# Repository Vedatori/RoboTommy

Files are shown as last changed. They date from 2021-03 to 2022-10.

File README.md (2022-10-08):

# Multifunkční robotická platforma RoboTommy
RoboTommy je open source projekt zamýšlený jako univerzální platforma pro začátečníky v robotice, elektronice a programování. Při návrhu byl kladen důraz na široké možnosti robota v kombinaci s nízkými nároky na kutila.

RoboTommy byl vytvořen jako projekt pro robotické lekce a letní tábory v SVČ Lužánky v Brně. Autory jsou Martin Ptáček, Petr Vávra, Martin Coufal a Marek Coufal.

Robotická platforma je založena na 3D tištěném šasi se dvěma DC motory řízenými H můstkem. Jako řídicí jednotka byla použita kombinace mikrokontrolérů Arduino Nano Atmega328 a Wemos D1 Mini ESP8266.

Pro přidání vlastních functionalit nebo upravení designu se přihlašte na onshape.com a vyhledejte si projekt "RoboTommy". Pro zobrazení elektronických schémat nebo upravení základní desky, navštivte [easyeda.com](https://easyeda.com/technika/Arduino_Nano_ESP_MPU_board-965e335938244bc3aa54cd378a177850).

## Licence

* Obsah tohoto repozitáře mimo složku *Software* je sdílen pod licencí [Attribution-NonCommercial-ShareAlike 4.0 International (CC BY-NC-SA 4.0)](https://creativecommons.org/licenses/by-nc-sa/4.0/).

* Obsah složky *Software* je sdílen pod licencí [GNU Lesser General Public License v3.0](https://www.gnu.org/licenses/lgpl-3.0.en.html).

# Multifunctional robotics platform RoboTommy [en]
RoboTommy is an open source project devoted to be a universal platform 
for robotics, electronics and programming beginners. In construction 
emphasis was placed on broad capabilities of the robot in combination 
with low demands on the tinkerer.

RoboTommy was created as a support tool for robotics classes and summer 
camps in SVC Luzanky in Brno by Martin Ptacek, Petr Vavra, Martin Coufal and Marek Coufal.

This robotics platform is based upon a 3D printed differential chassis with two 
DC engines controlled by a H bridge. For control purposes a combination of 
Aruino Nano Atmega328 and Wemos D1 Mini ESP8266 microcontrollers is used.

To add custom mechanical features or edit RoboTommy please visit onshape.com, log in and search for the "RoboTommy" project. To check the electronical schematics and control the MainBoard layout, please visit [easyeda.com](https://easyeda.com/technika/Arduino_Nano_ESP_MPU_board-965e335938244bc3aa54cd378a177850).

## License
* The contents of this repository excluding folder *Software* is shared under license [Attribution-NonCommercial-ShareAlike 4.0 International (CC BY-NC-SA 4.0)](https://creativecommons.org/licenses/by-nc-sa/4.0/).
* The contents of the folder *Software* is shared under license [GNU Lesser General Public License v3.0](https://www.gnu.org/licenses/lgpl-3.0.en.html).

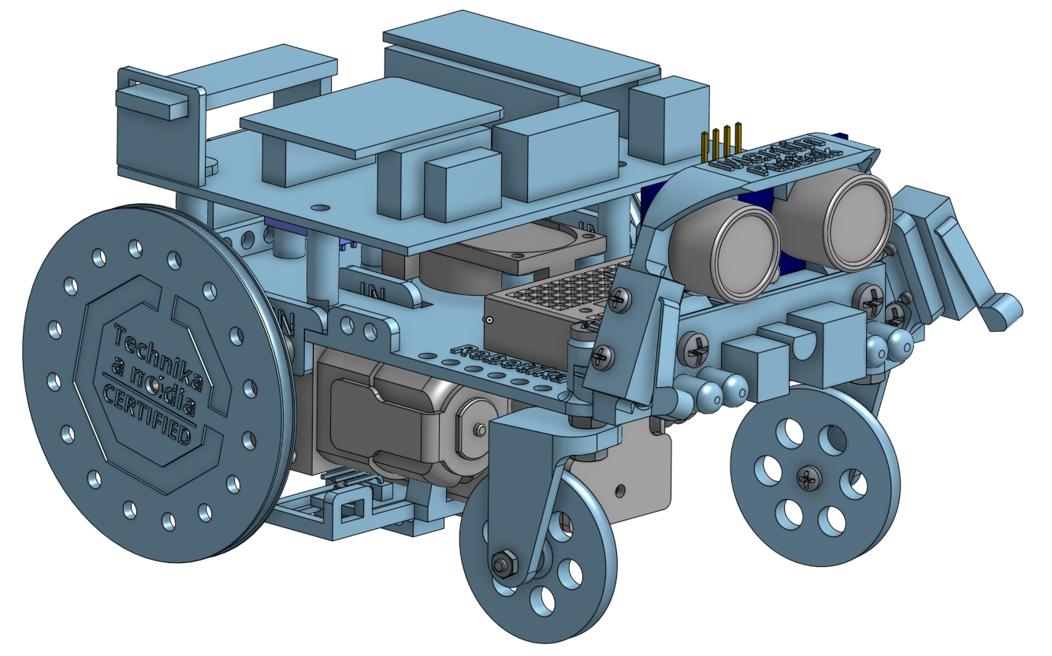
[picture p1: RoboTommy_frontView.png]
1.

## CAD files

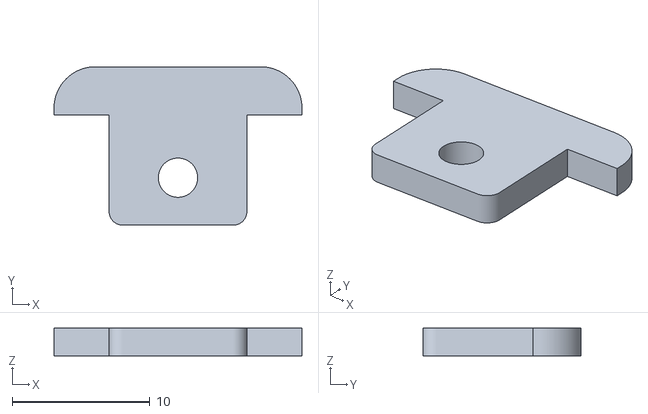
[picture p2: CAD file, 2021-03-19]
3DPrintParts_OnShape/EngineHolderIn.stl
18.0 x 11.5 x 2.00

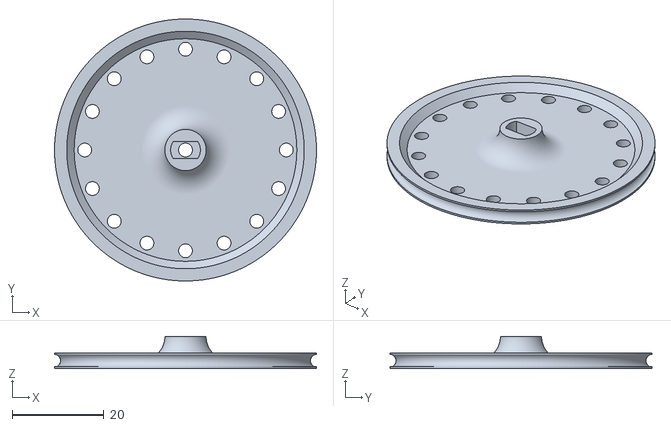
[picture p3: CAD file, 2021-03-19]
3DPrintParts_OnShape/RearWheel - Part 1 (5).stl
57.2 x 57.2 x 7.00

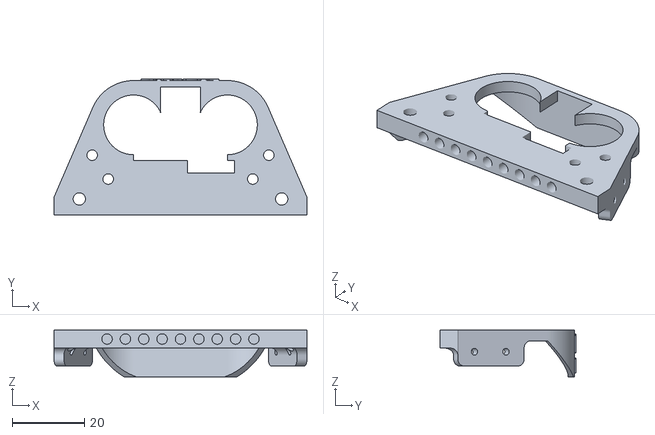
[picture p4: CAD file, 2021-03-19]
3DPrintParts_OnShape/UltrasonicHolder - Part 1 (2).stl
70.0 x 37.7 x 13.0

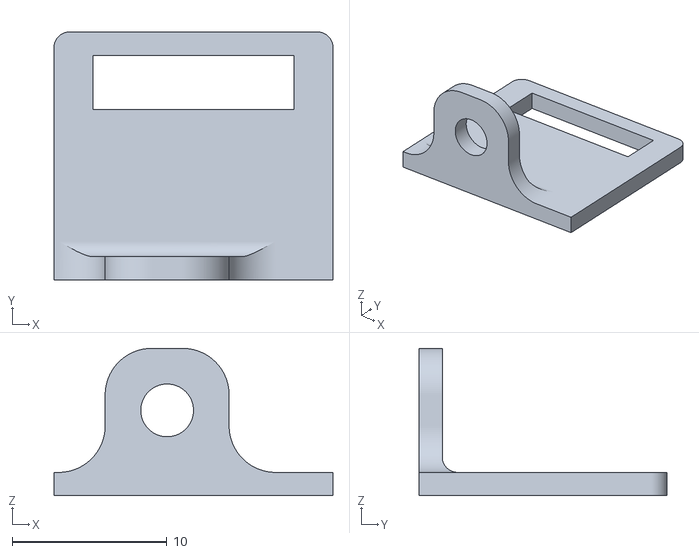
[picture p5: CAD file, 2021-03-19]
3DPrintParts_OnShape/DisplayHolder - Part 1.stl
18.0 x 16.0 x 9.50

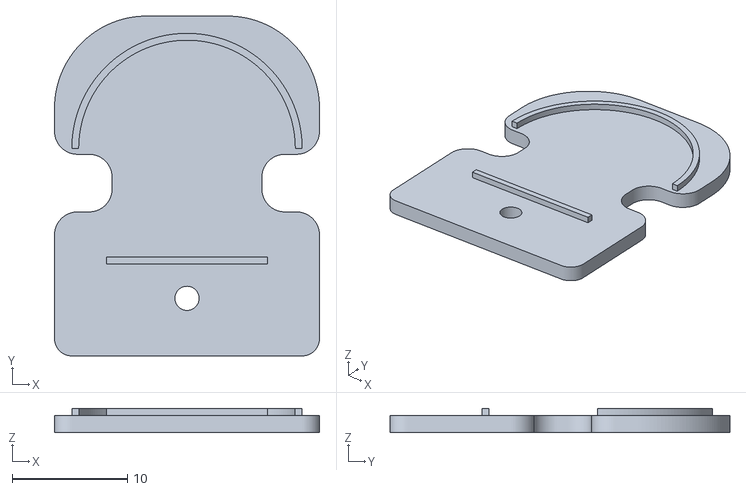
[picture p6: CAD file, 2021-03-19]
3DPrintParts_OnShape/PowerPackCover.stl
23.0 x 29.5 x 2.10

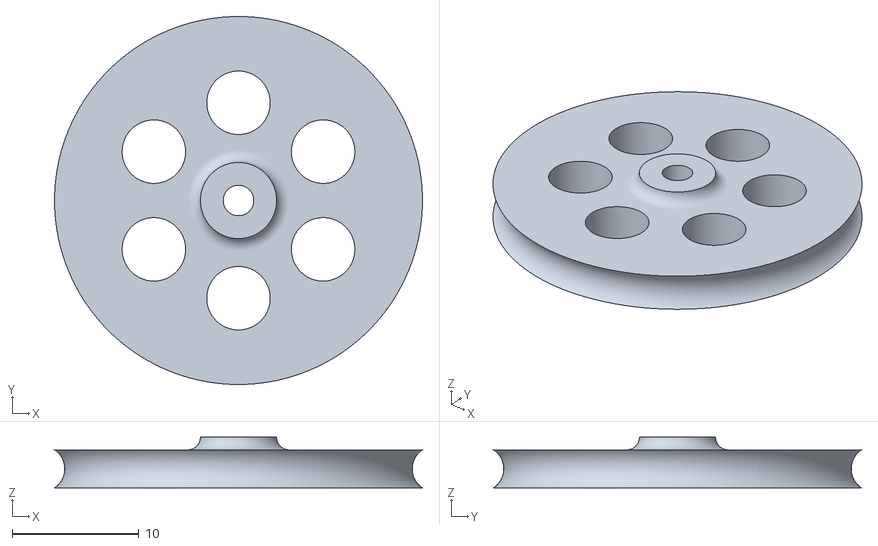
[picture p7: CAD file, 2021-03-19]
3DPrintParts_OnShape/FrontWheel - Part 1 (4).stl
29.0 x 29.0 x 4.00

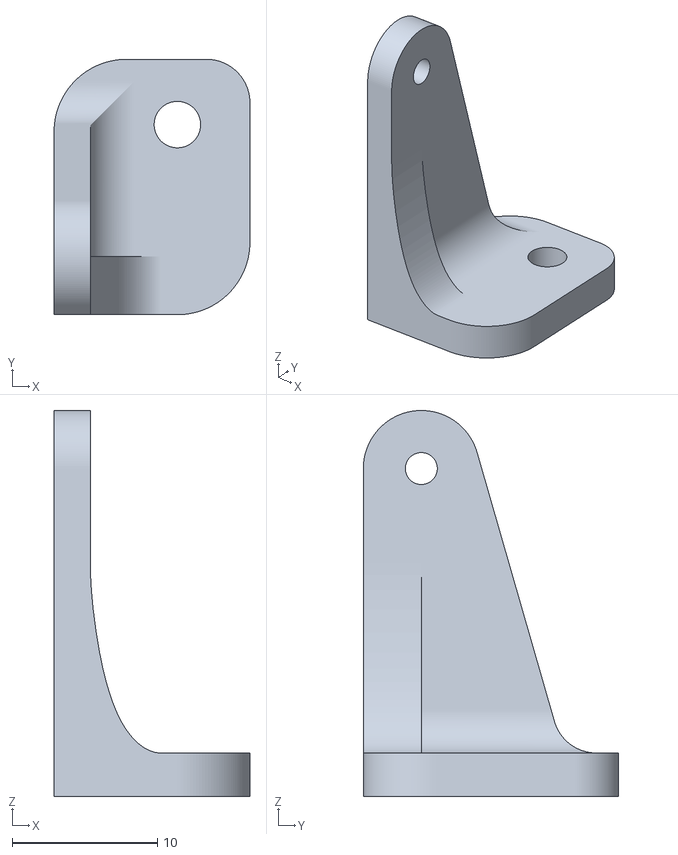
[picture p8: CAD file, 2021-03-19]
3DPrintParts_OnShape/FrontWheelHolder - Part 1 (1).stl
13.5 x 17.6 x 26.6

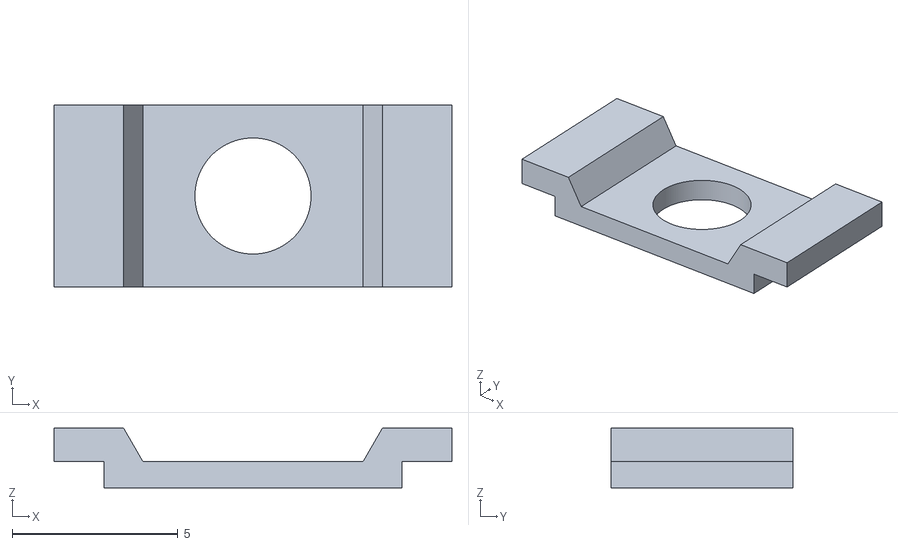
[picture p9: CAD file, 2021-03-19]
3DPrintParts_OnShape/CNY70Fastener - Part 1.stl
12.0 x 5.50 x 1.80

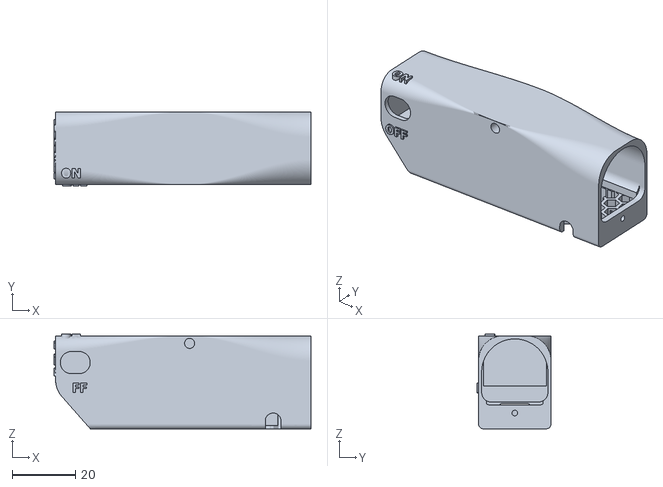
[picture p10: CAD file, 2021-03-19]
3DPrintParts_OnShape/PowerPackHolder.stl
81.5 x 23.5 x 30.0

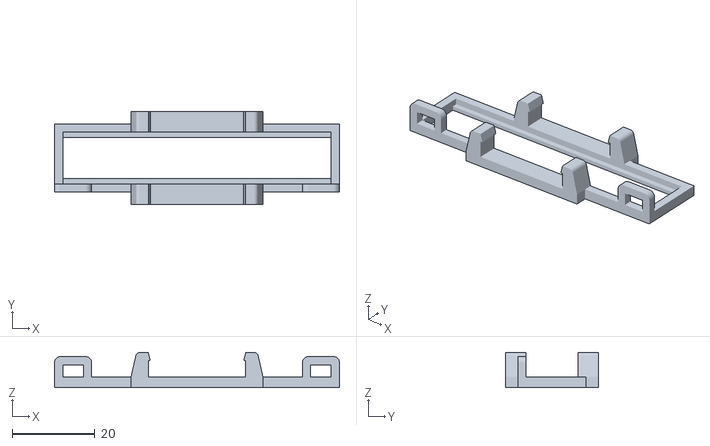
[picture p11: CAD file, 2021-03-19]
3DPrintParts_OnShape/CNY70Holder - Part 1 (1).stl
69.0 x 22.5 x 8.50

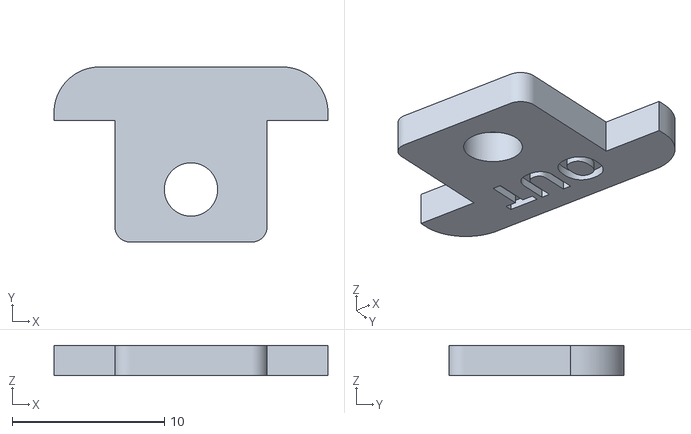
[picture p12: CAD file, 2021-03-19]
3DPrintParts_OnShape/EngineHolderOut.stl
18.0 x 11.5 x 2.00

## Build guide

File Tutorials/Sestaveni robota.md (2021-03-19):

# Montáž minimální konfigurace RoboTommy

*TODO: Doplnit rozměry šroubů, názvy korespodujících stl součástí, názvy elektronických součástí + whereToBuy*
## Součásti

1. **2x kolo, gumička, šroubek**
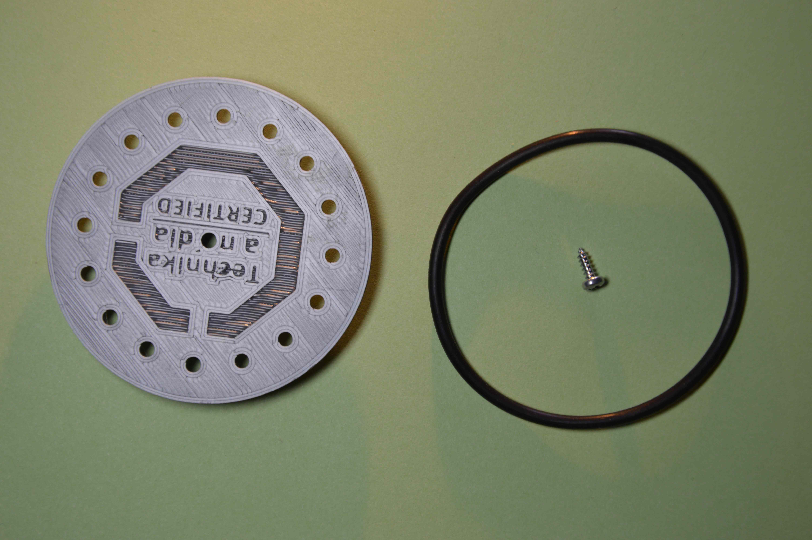
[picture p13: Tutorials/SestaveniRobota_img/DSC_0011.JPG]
    
2. **1x Main Board**

    *povinné součásti pro funkčnost*
    1. svorky napájení 
    2. svorky motorů
    3. připájený DRV 8833 Motor Driver
    4. dutinkové lišty pro Arduino Nano + Arduino Nano
    5. 3x šrouby pro připevnění na nosnou desku
   
    *volitelné součásti*
    1. Senzor vlhkosti a teploty DHT12
    2. dutinkové lišty pro Wemos D1 MINI + Zenerovy diody a odpory + Wemos D1 MINI
    3. dutinkové lišty pro gyroskop (napájené zespodu) + gyroskop
    4. Gesture senzor
    5. OLED displej 128x32

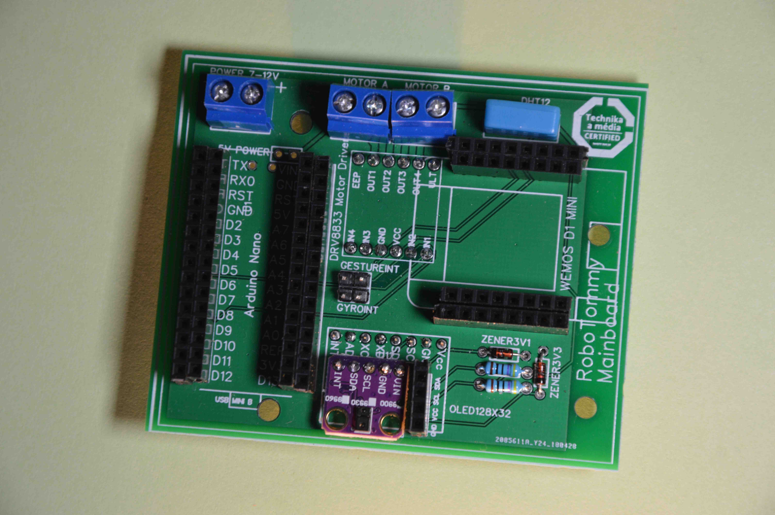
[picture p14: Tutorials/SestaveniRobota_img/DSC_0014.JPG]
    
3. **1x nosná deska s nepájivým polem**
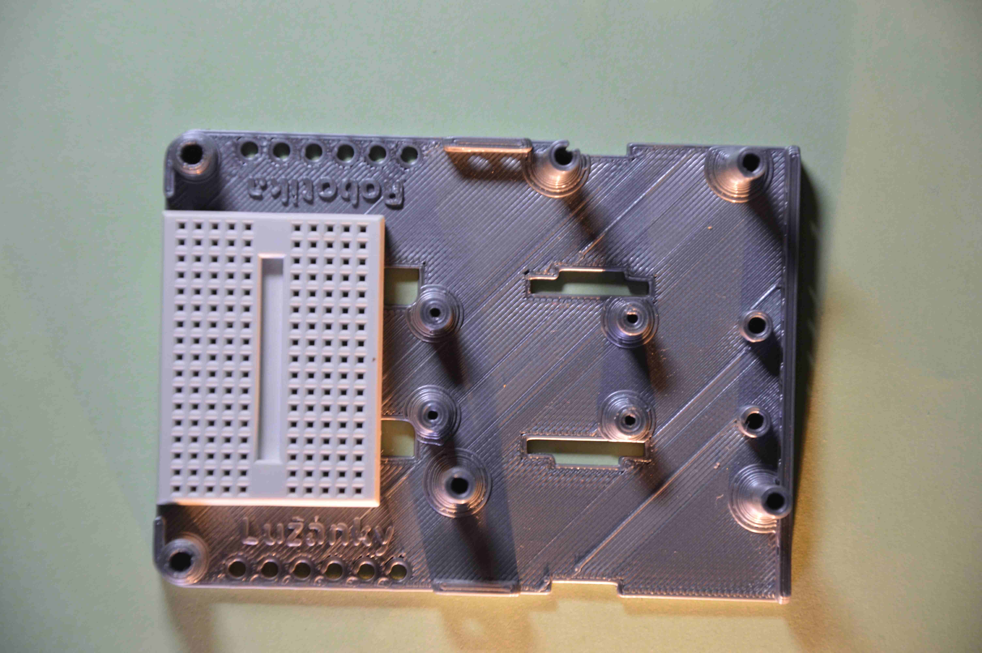
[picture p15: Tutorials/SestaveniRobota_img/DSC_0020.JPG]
    
4. **1x Power Pack** 
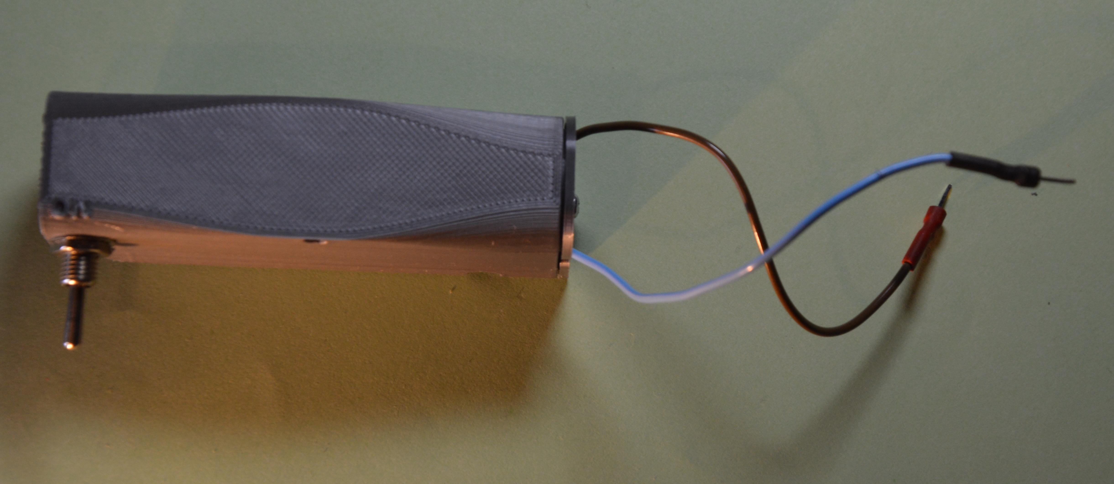
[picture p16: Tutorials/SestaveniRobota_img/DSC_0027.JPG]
    
5. **2x motor, 4x úchyt, 2x uchycovací šroub a matka**
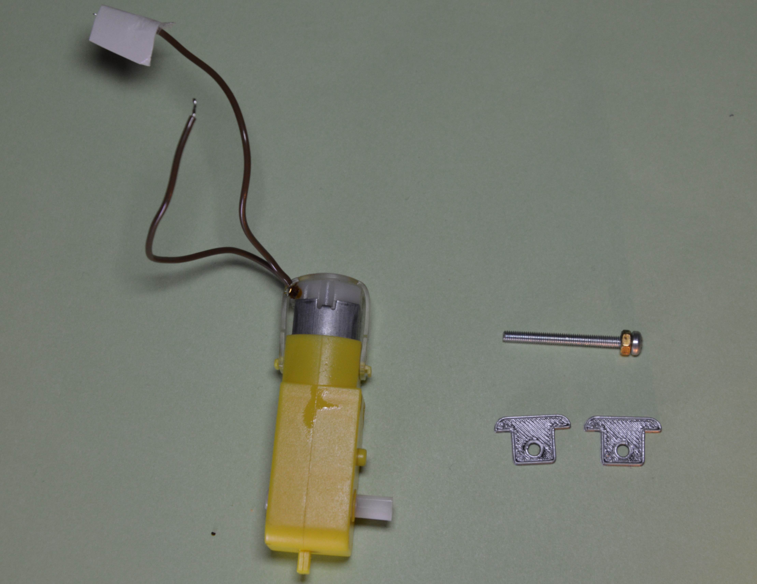
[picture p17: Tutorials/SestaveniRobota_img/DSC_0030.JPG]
    
6. **2x závěs předního kola, 2x kolo, 2x uchycovací šroub, 4x matka, 2x gumička, 2x uchycovací šroub, 4x matka**
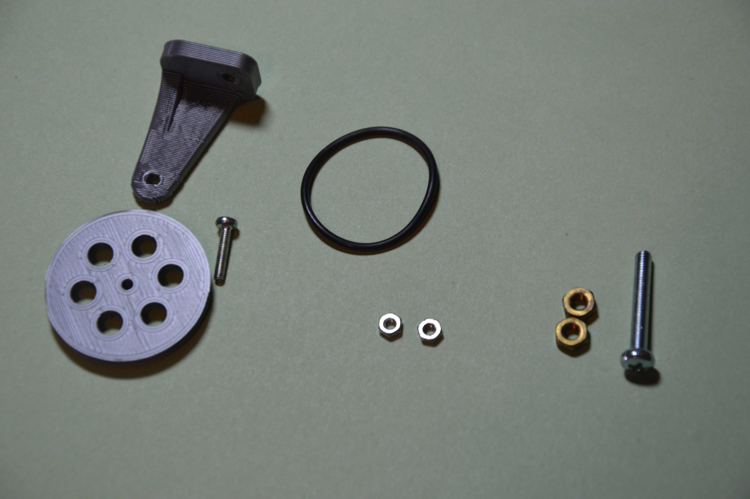
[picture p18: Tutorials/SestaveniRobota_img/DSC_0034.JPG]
    

## Proces montáže

### Montáž závěsu předního kola

Pro tuto část je třeba součásti z bodů 6 a 1 části Součásti tohoto dokumentu.

<<<<<<< HEAD
1. Navléct gumičku na kolo, provléct šroub kolem, z druhé strany našroubovat matku. *Matka nebude v kontaktu s kolem, je nutné zachovat malou mezeru.*
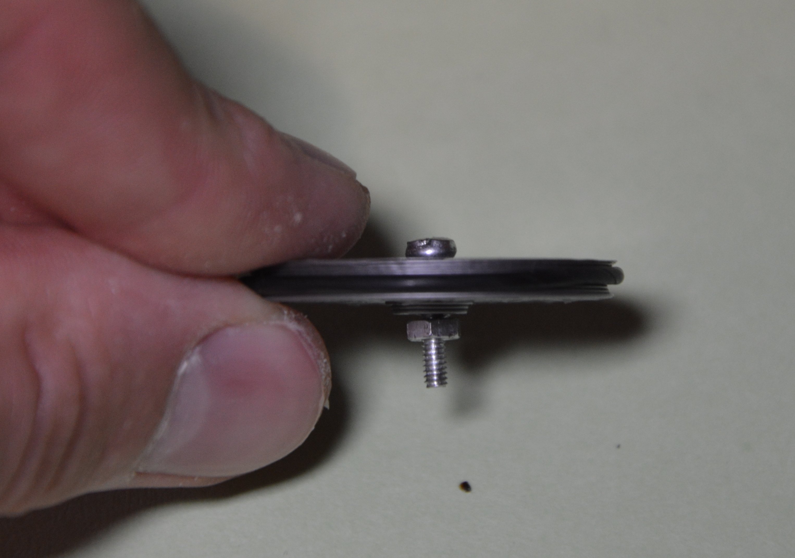
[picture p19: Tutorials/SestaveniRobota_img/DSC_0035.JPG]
    
=======
1. Navléct gumičku, provléct šroub kolem, z druhé strany našroubovat matku. *Matka nebude v kontaktu s kolem, je nutné zachovat malou mezeru.*
    
>>>>>>> fd59f11337bc10f44106d7633502139bb4ab0da0
2. Konec šroubu provléct závěsem a na konci přišroubovat matku. *Obě matky budou dotaženy ve směru šipek na obrázku, směrem k závěsu kola, kolo by se mělo volně protáčet.*
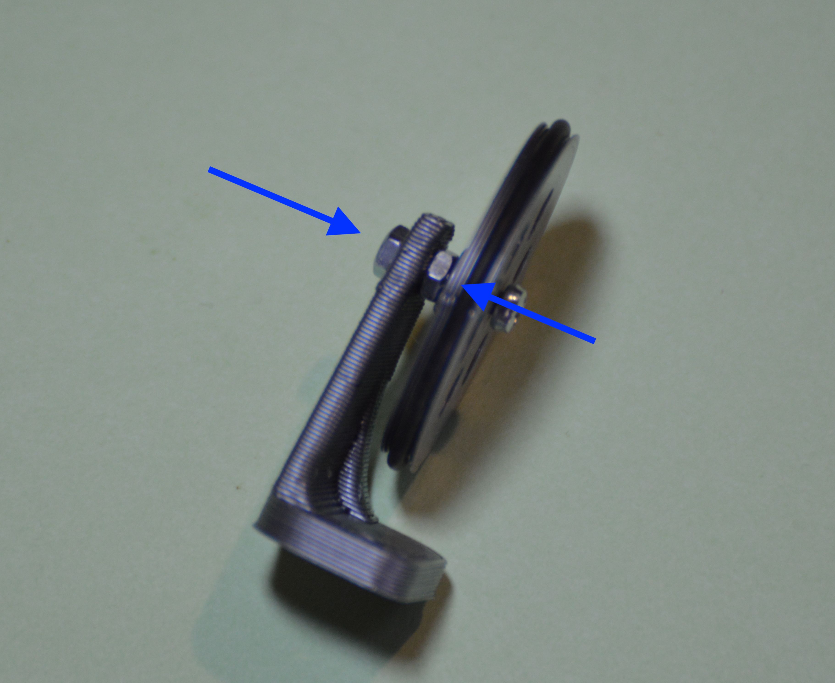
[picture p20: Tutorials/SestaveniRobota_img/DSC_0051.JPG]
    
3. Nosnou deskou protáhnout šroub, přšroubovat na něj matku. *Matka nebude v kontaktu s deskou, je nutné zachovat malou mezeru. Šroub se musí v desce volně protáčet.*
<<<<<<< HEAD
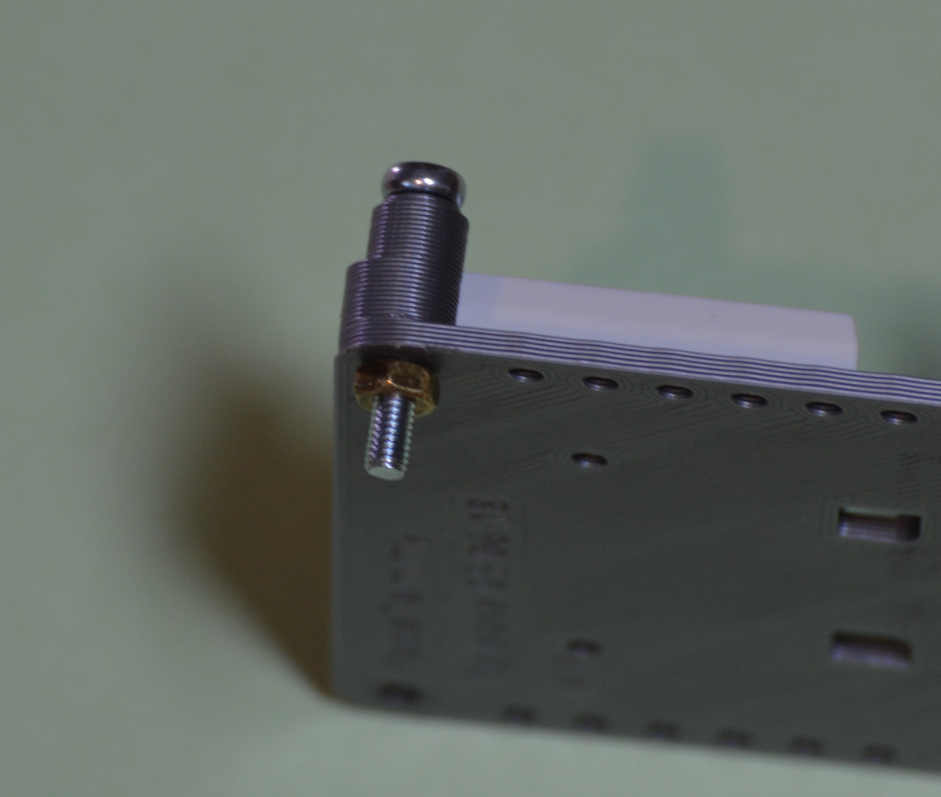
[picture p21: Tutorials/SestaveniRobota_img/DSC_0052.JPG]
    
4. Za matku navléct na šroub závěs kola a dotáhnout matky, aby byly v kontaktu pouze se závěsem a šroub se mohl v nosné desce volně protáčet.
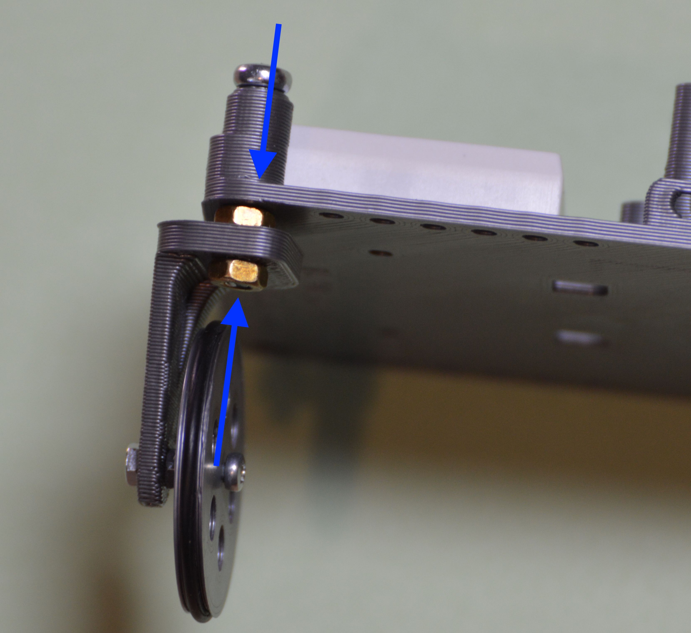
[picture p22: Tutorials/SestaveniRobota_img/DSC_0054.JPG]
    
=======
    
4. Za matku navláct na šroub závěs kola a dotáhnout matky, aby byly v kontaktu pouze se závěsema a šroub se mohl v nosné desce volně protáčet.
    
>>>>>>> fd59f11337bc10f44106d7633502139bb4ab0da0
5. **Postup opakovat pro druhé přední kolo.**
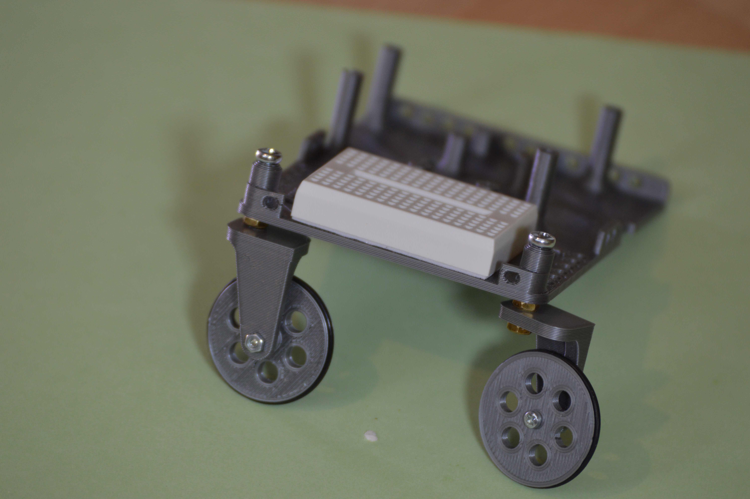
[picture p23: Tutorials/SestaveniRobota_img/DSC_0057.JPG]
    

### Montáž motorů, zadních kol a Power Packu

<<<<<<< HEAD
1. Nosnou desku nasměrovat trubičkami pro uchycení šroubů k zemi. 
2. Na šroub namontovat matku a jeden úchyt, tuto sestavu umístit do odpovídajícho výřezu na nosné desce. Šroub protáhnout skrze motor. *Vodič, který je na motoru nyní blíže k nosné desce, označit páskou.*  Z motoru odvést vodiče skrze přilehlou díru na druhou stranu nosné desky. 
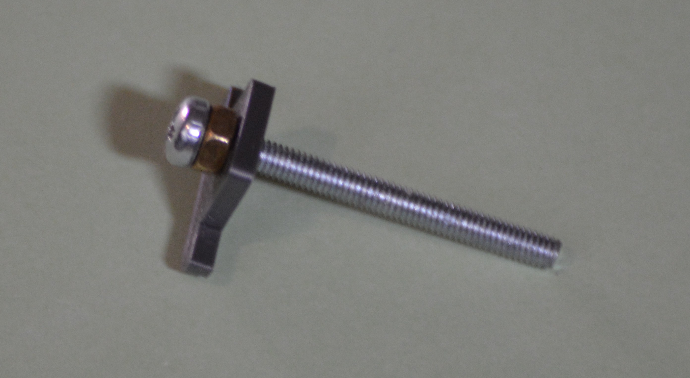
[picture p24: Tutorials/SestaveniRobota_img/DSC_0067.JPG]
    
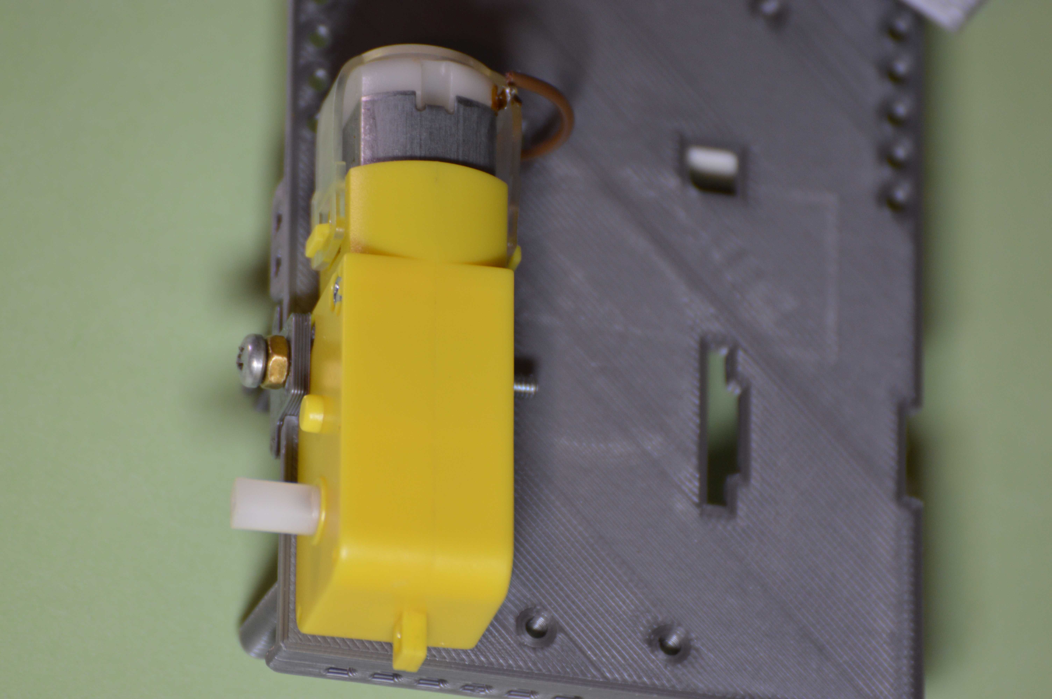
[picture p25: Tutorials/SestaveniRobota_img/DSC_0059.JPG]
    
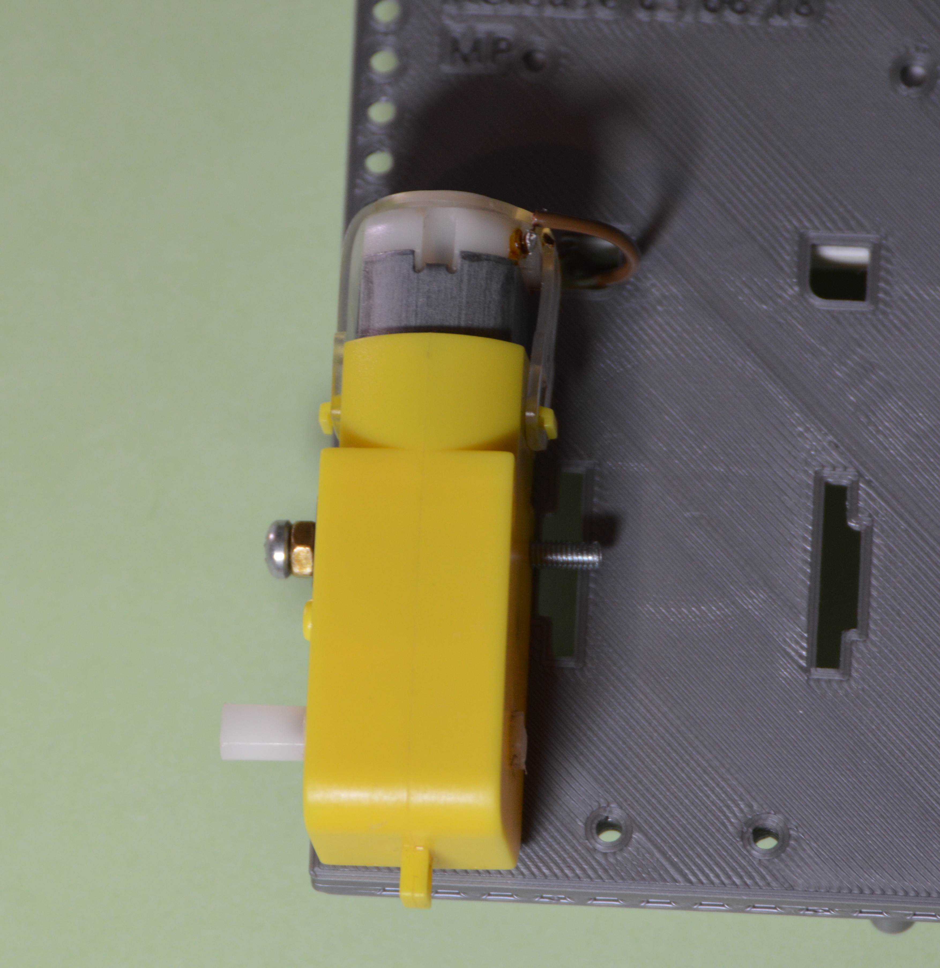
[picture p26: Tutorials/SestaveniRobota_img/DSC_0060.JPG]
    
3. Do příslušného výřezu na desce umístit druhý úchyt a přidržovat jej ve správné poloze. Postupným otáčením šroubu přitáhnout druhý úchyt do správné pozice, úchyt při šoubování pevně držet ve vodorovné pozici.
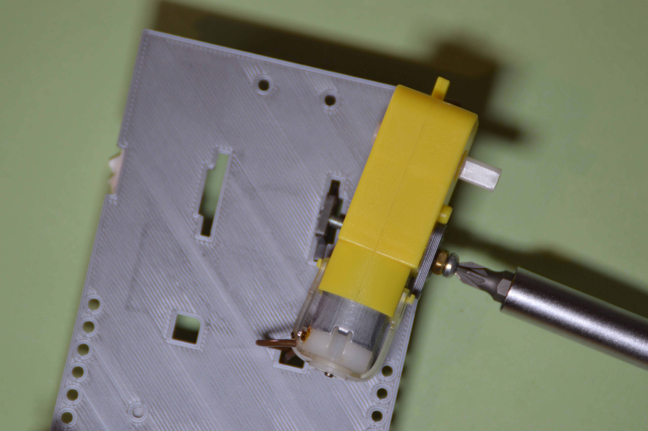
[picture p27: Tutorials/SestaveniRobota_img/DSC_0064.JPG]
    
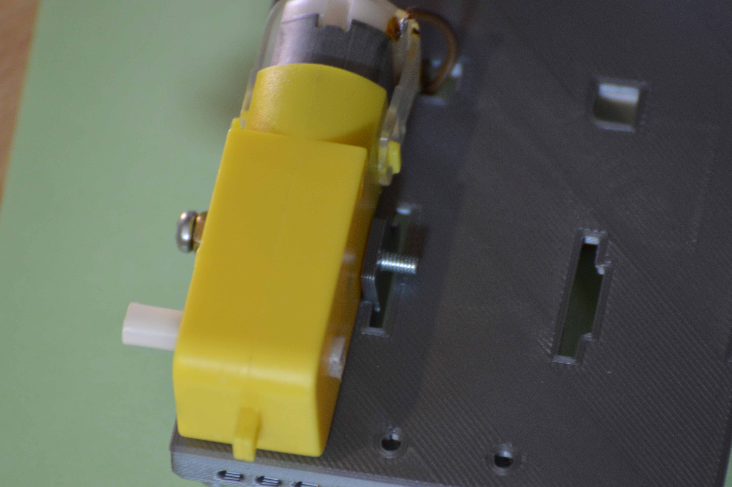
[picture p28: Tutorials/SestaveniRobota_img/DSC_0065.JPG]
    
4. Na konec šroubu nasunout Power Pack. Vodiče Power Packu odvést na druhou stranu nosné desky, každý jendou bližší dírou.
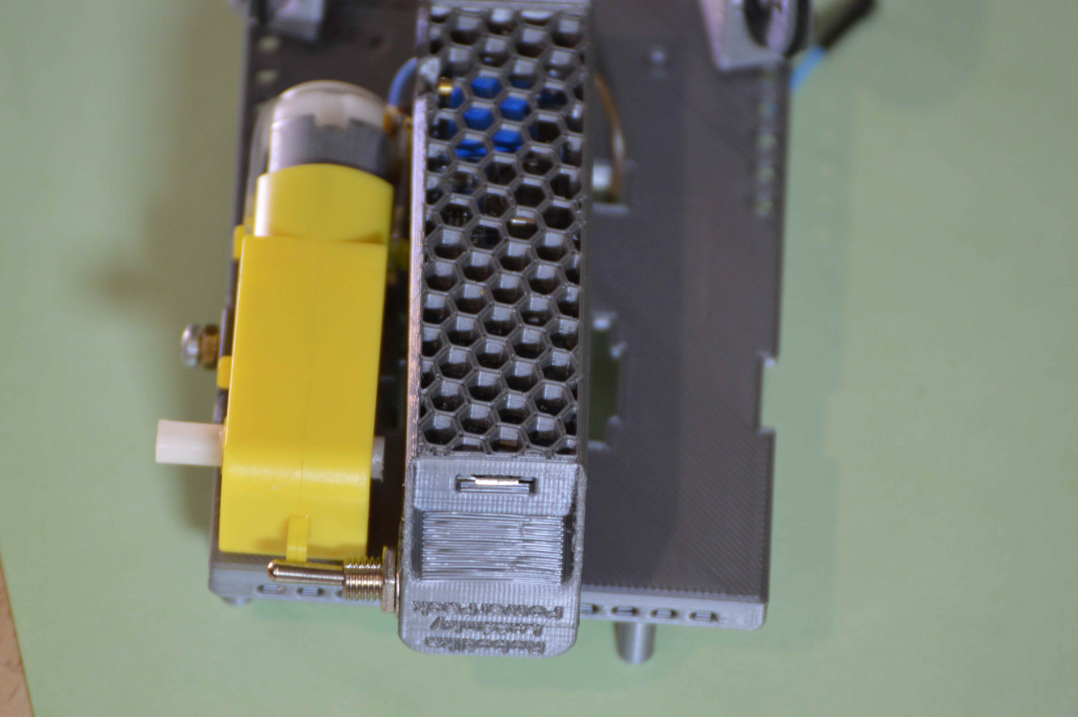
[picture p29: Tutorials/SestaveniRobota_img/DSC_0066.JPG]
    
5. Pro připevnění druhého motoru opakujte postup v krocích 1 a 2.
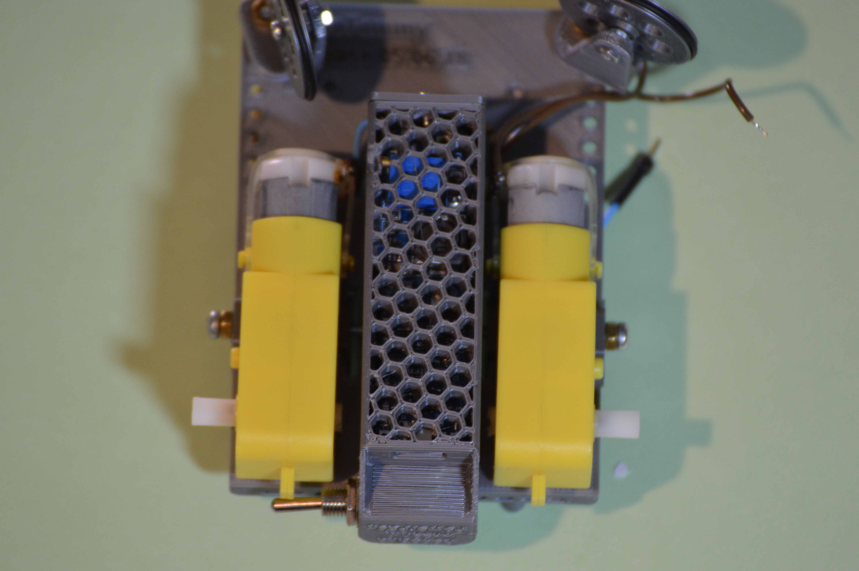
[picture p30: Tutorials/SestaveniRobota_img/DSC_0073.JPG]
    
6. Na obě zadní kola navléct gumičku.
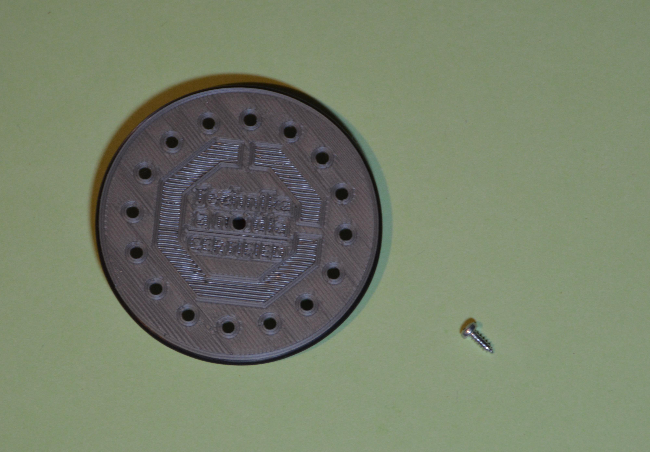
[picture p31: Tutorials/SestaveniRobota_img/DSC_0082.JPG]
    
7. Na každý z motorů nasunout zadní kolo a přišroubovat šroubkem.
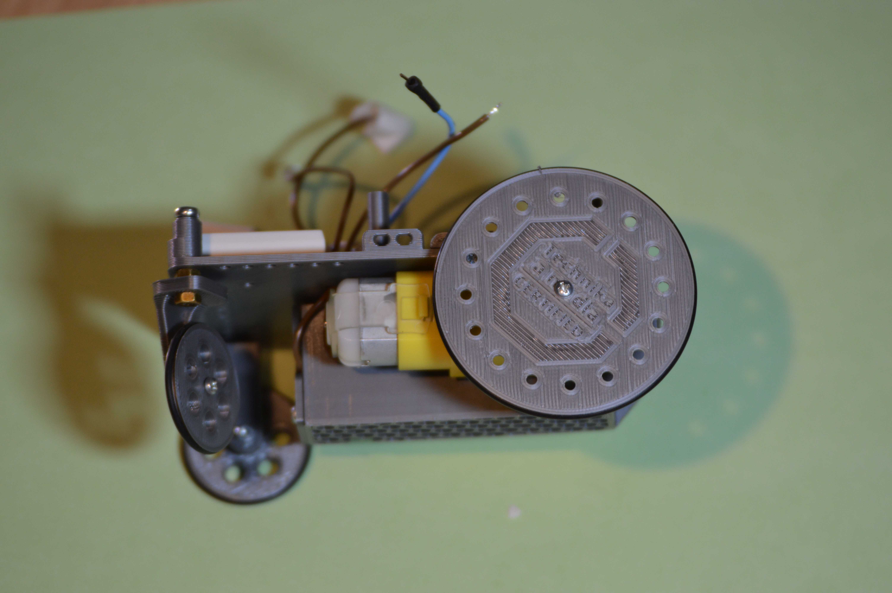
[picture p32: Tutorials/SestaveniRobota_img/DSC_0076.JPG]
    
8. Postavit RoboTommy na kola.
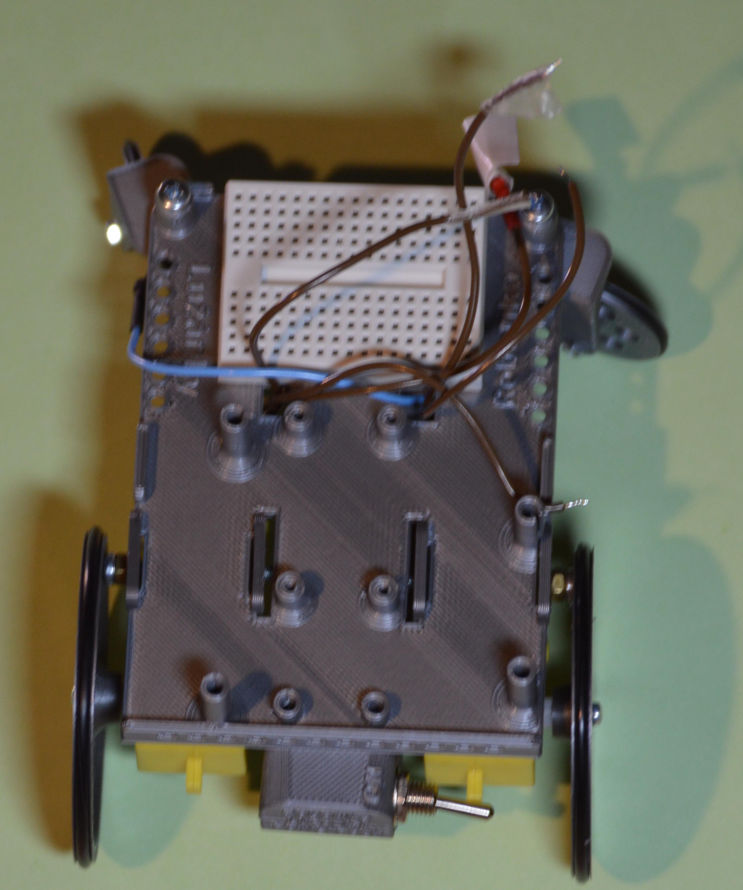
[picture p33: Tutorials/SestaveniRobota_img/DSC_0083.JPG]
    
=======
1. Nosnou desku nasměrovat trubičkami pro uchycení šroubů k zemi. Na šroub namontovat matku a jeden úchyt, tuto sestavu umístit do odpovídajícho výřezu na nosné desce. Šroub protnout skrze motor. Z motoru odvést vodiče skrze přilehlou díru na druhou stranu desky. *Vodič, který je na motoru nyní blíže k nosné desce, označit páskou.* 
    
    
    
2. Do příslušného výřezu na desce umístit druhý úchyt a přidržovat jej ve správné poloze. Postupným otáčením šroubu přitáhnout druhý úchyt do správné pozice, úchyt při šoubování pevně držet ve vodorovné pozici.
    
    
3. Na konec šroubu nasunout Power Pack. Vodiče Power Packu odvést na druhou stranu nosné desky, každý jendou bližší dírou.
    
4. Pro připevnění druhého motoru opakujte postup v krocích 1 a 2.
    
5. Na obě zadní kola navléct gumičku.
    
6. Na každý z motorů nasunout zadní kolo a přišroubovat šroubkem.
    
7. Postavit RoboTommy na kola.
    
>>>>>>> fd59f11337bc10f44106d7633502139bb4ab0da0

### Montáž Main Board

Následující část předpokládá úspěšné osazení Power Packem a motory.

1. Přišroubovat gyroskop pomocí šroubu na levé stráně k nosné desce. *Pravý šroub ponechat neosazen, hrozí zničení rezistoru.*
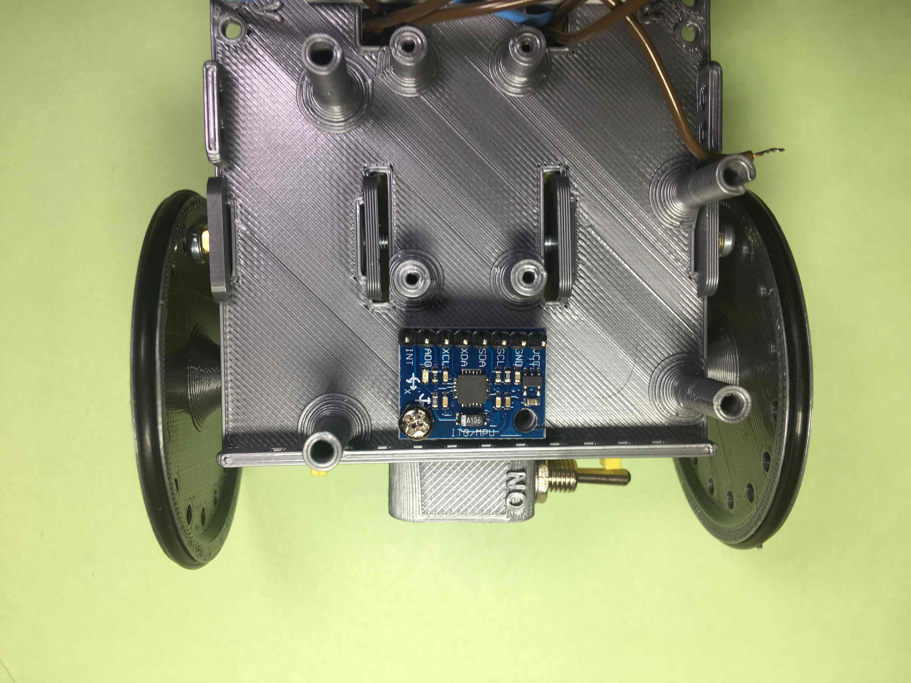
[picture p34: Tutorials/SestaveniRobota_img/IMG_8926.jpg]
    
2. Propojit gyroskop a Main Board.
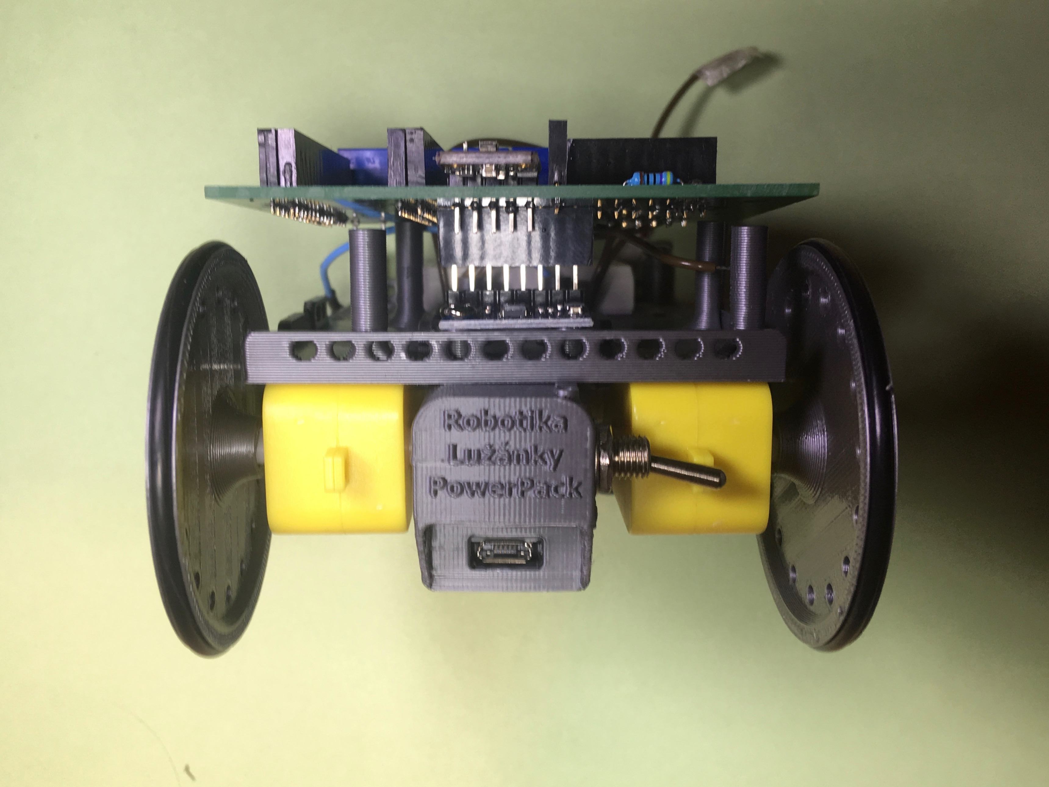
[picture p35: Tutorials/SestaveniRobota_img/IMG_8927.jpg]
    
3. Přišroubovat Main Board na nosnou desku.
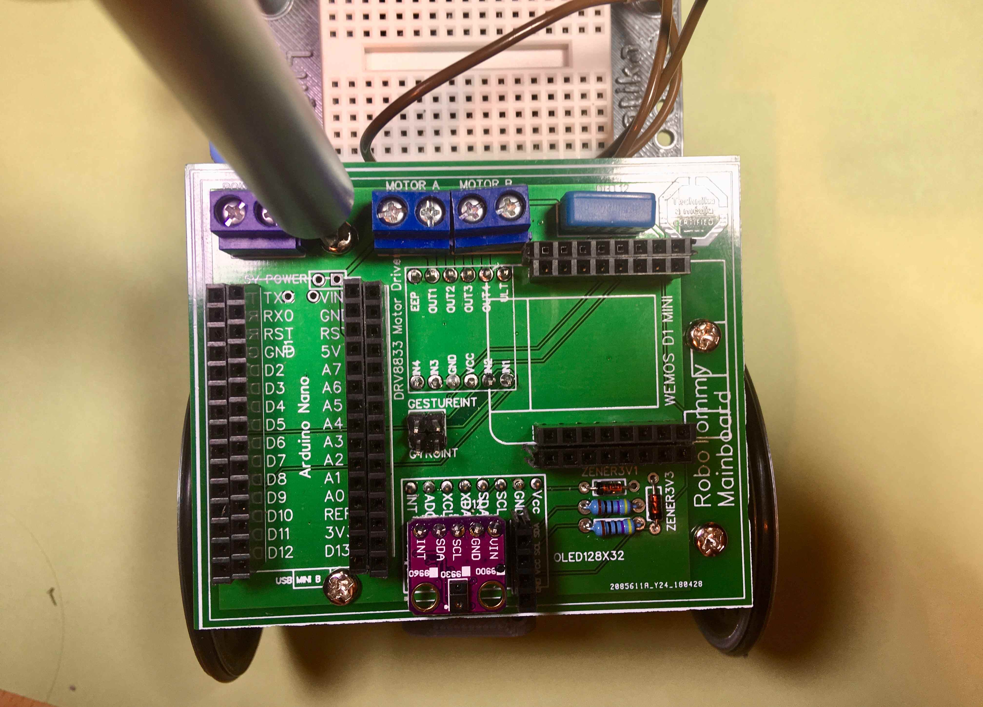
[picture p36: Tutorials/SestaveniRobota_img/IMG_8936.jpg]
    
4. Main Board osadit Arduino Nano, do svorkovnice vlevo připojit Power Pack. Do svorkovnice Motor A připojit levý motor při pohledu shora, pravý motor do svorkovnice Motor B. Označené vodiče boudou v příslušné svorkovnici vždy vlevo.
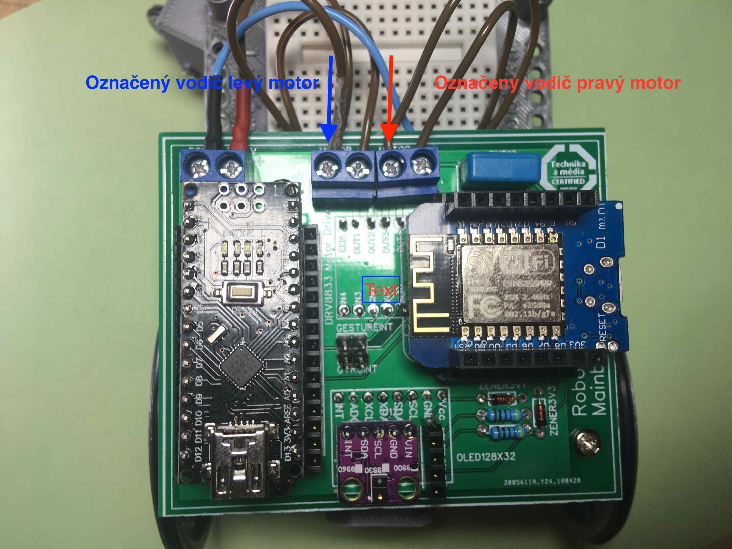
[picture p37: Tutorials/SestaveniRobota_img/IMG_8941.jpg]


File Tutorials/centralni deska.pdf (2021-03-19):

## Senzor osvětlení s LED

Pracovní postup:
Osazovat budeme podle velikosti součástek, tzn. že jako první budeme pájet nejmenší komponenty.

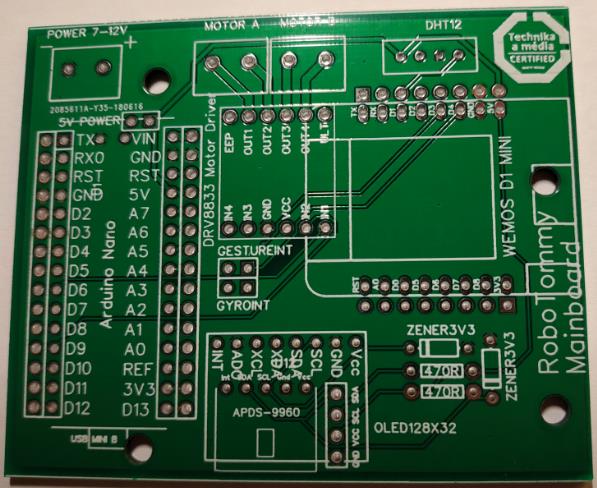
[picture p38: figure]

Jako první zapájíme rezistory. Oba mají hodnotu 470 Ω a nemají polaritu.

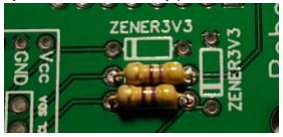
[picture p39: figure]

Nyní osadíme Zenerovy diody. Pozor na polaritu, černý pruh na diodě musí při osazení odpovídat bílému pruhu na potisku desky. Správné zapojení tedy je:

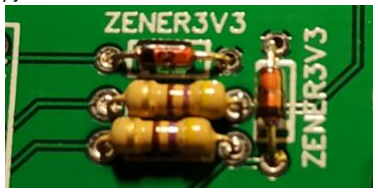
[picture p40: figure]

Do některých komponentů (jako např. gesture sensor) na tuto desku je potřeba předem zapájet kolíkové lišty. Pozor na jejich směr (nahoru/dolů, některé součástky budou osazeny zespodu):

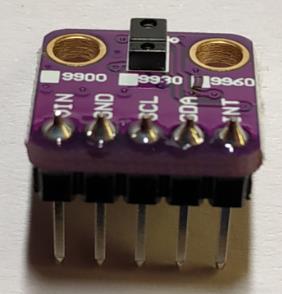
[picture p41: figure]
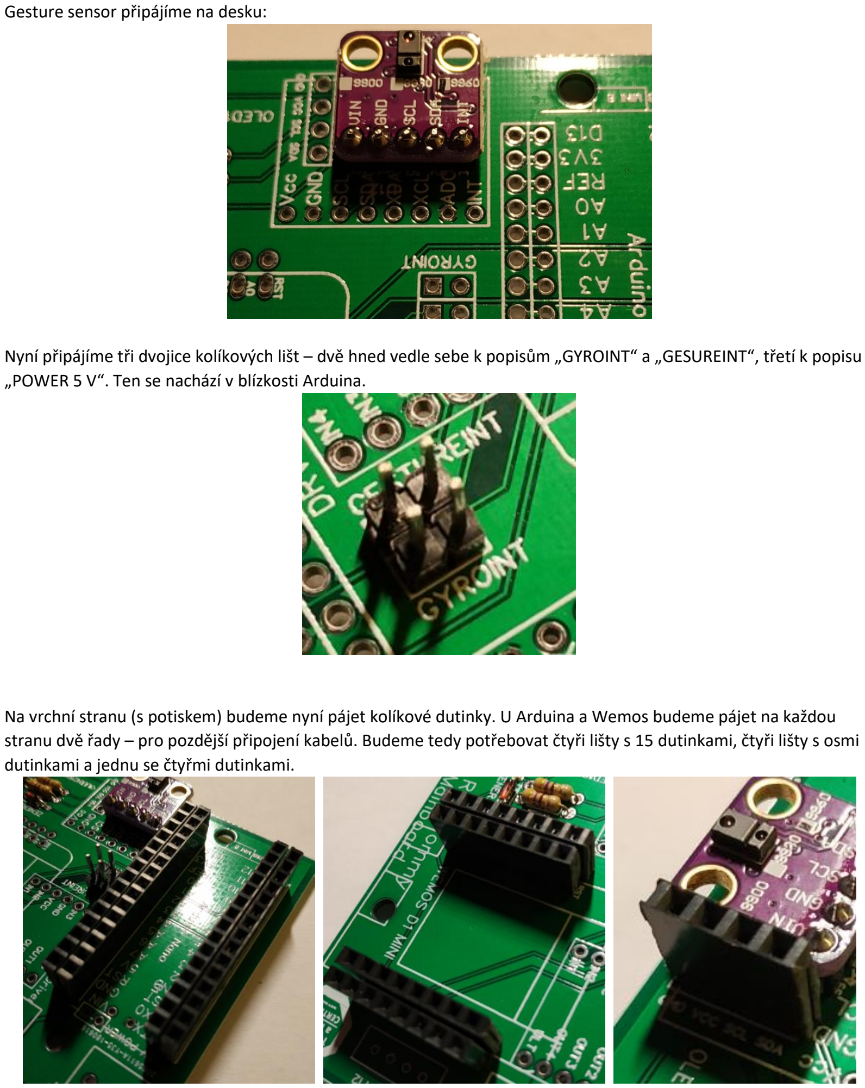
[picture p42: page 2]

Gesture sensor připájíme na desku:

Nyní připájíme tři dvojice kolíkových lišt – dvě hned vedle sebe k popisům „GYROINT“ a „GESUREINT“, třetí k popisu „POWER 5 V“. Ten se nachází v blízkosti Arduina.

Na vrchní stranu (s potiskem) budeme nyní pájet kolíkové dutinky. U Arduina a Wemos budeme pájet na každou stranu dvě řady – pro pozdější připojení kabelů. Budeme tedy potřebovat čtyři lišty s 15 dutinkami, čtyři lišty s osmi dutinkami a jednu se čtyřmi dutinkami.

Nyní připájíme senzor teploty a vlhkosti DHT 12. Pozor na jeho orientaci, musí směřovat tak, aby byl zvenku viditelný jeho nápis:

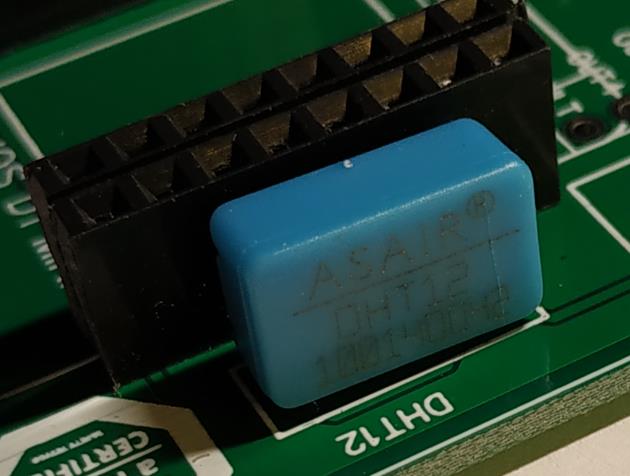
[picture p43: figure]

Dále budeme pájet z druhé strany desky. Nejdříve spojíme dva kontakty na H můstku DRV 8833 označené „J2“. Tento krok je nutno udělat nyní, později se k této straně obvodu nedostaneme.

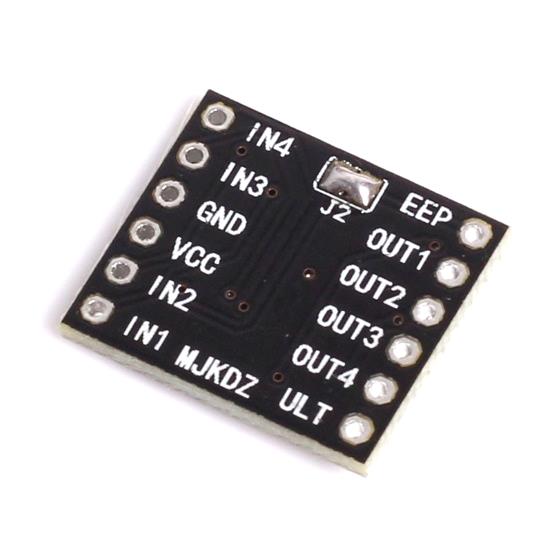
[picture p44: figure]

Dále si připájíme kolíkové lišty na DRV 8833:

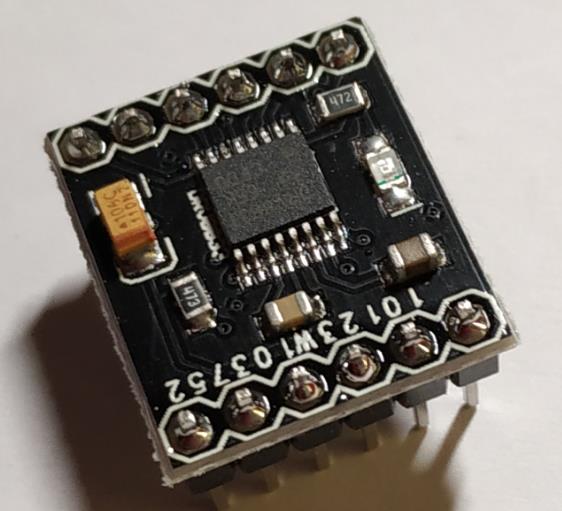
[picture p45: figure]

DRV 8833 následně připájíme na spodní stranu desky a poté odstříháme nadměrně dlouhé vývody:

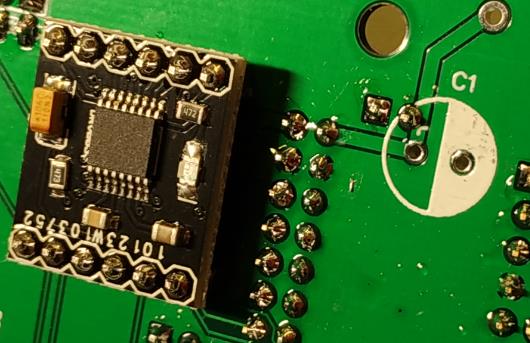
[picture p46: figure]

Zespodu zapájíme i dutinkovou lištu s osmi dutinkami, která bude později připojena ke gyroskopu:

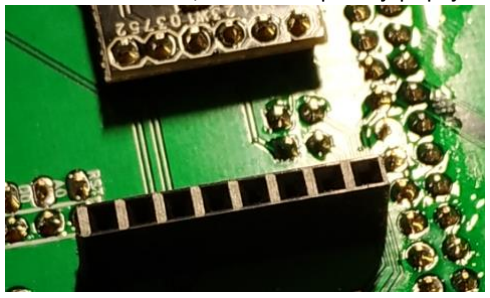
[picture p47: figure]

Nyní se vrátíme k vrchní straně desky a zapájíme konektory se šroubky. Pro osazení dvou sousedících je potřebné je nejdříve zaklesnout do sebe.

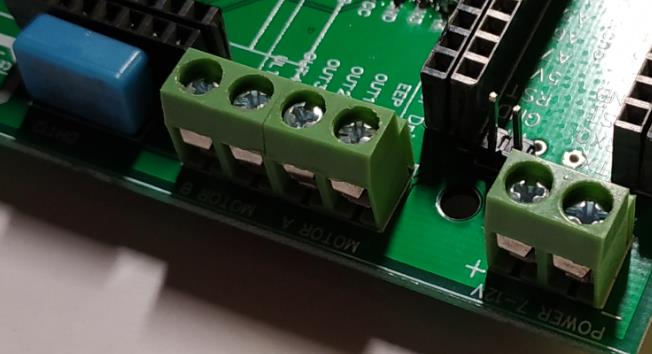
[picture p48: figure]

Jako poslední do dutinkových lišt vložíme Arduino a Wemos:

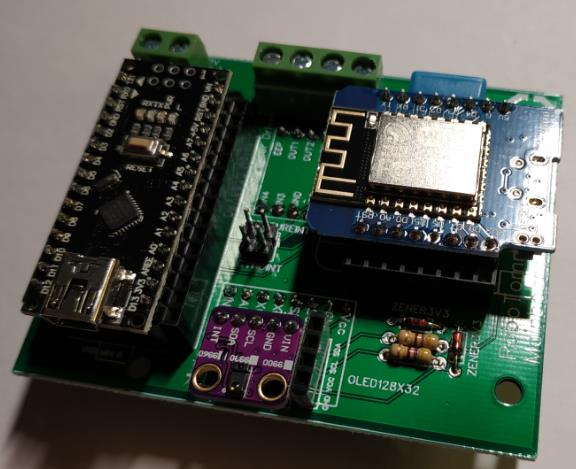
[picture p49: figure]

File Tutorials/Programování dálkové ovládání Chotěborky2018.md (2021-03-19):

# Návod na programování RoboTommy - dálkové ovládání

V tomto návodě je popsána instalace vývojového prostředí, nahrání připravených programů z letního tábora a také zprovoznění samotného dálkového ovládání platformy RoboTommy. Pro dálkové ovldání je Robotommy připojen ke stejné WiFi síti jako PC s ovládacím programem.

Pro programování RoboTommy je použito vývojové prostředí Visual Studio Code s rozšířením PlatformIO. Pro instalaci prostředí a rozšíření můžete použít tento [návod](https://docs.platformio.org/en/latest/ide/vscode.html#installation), jehož hlavní část je na obrázku níže:

<figure>
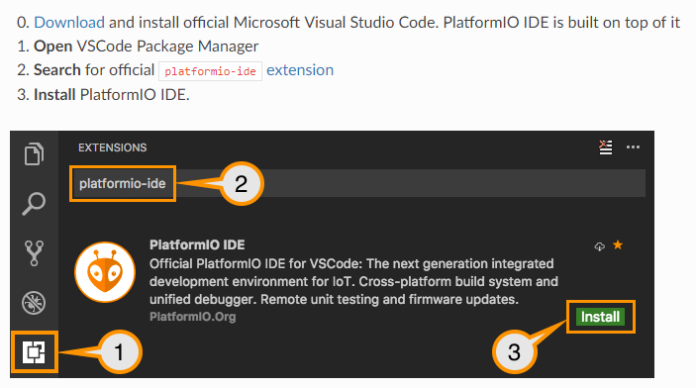
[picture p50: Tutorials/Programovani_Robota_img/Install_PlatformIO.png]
    
    <figcaption></figcaption>
</figure>

## Arduino Nano ATmega328
Nejdříve naprogramujeme koncový mikrokontrolér Arduino Nano. Projekt programu otevřeme v VS Code pomocí File->Open Folder->Zvolíme cestu "RoboTommy\Software\Chotěborky_2018_Remote_Control\Arduino". Tento program je možné bez úprav nahrát do RoboTommy. Arduino Nano zasunuté do MainBoardu připojíme k PC pomocí USB Mini B kabelu. V případě použití neoriginálního Arduino klona je třeba nainstalovat [driver CH340](https://sparks.gogo.co.nz/ch340.html). Dobrou praxí je ujistit se, že je Arduino detekováno ve Windows Správci zařízení. 

V levém spodním rohu VS Code se nachází panel PlatformIO. Je zde i tlačítko pro kompilaci a nahrání programu do Arduina (šipka směřující vpravo). Lze použít i klávesovou zkratku CTRL+ALT+U. V případě, že je připojeno více USB zařízení, budete ve spodním terminálu vyzvání k napsání názvu portu, pod kterým je Arduino vedeno, např. "COM11". Úspěšné nahrání programu je značeno velkým nápisem "SUCESS" na spodním terminálu.

## ESP8266 WEMOS D1 mini
Obdobným způsobem otevřeme projekt programu pro WiFi modul ESP8266: File->Open Folder->Zvolíme cestu "RoboTommy\Software\Chotěborky_2018_Remote_Control\ESP". V tomto projektu je třeba změnit přihlašovací údaje lokální WiFi sítě. K tomu otevřeme soubor "WifiHandler.h" a přepíšeme údaj v uvozovkách "Your_SSID" na jméno lokální WiFi sítě a "Your_password" na její heslo. Uvozovky je nutné zachovat:

<figure>
    
    <figcaption></figcaption>
</figure>

Pomocí CTRL+ALT+U nahrajeme program do ESP8266 připojeného k PC pomocí micro USB kabelu. Po nahrání programu signalizovaného nápisem "SUCCESSL je vhodné ES8266 resetovat pomocí bočního tlačítka na WEMOS modulu (nalevo od nápisu RESET). Poté by měla OLED obrazovka zobrazit úvodní loga, následně název WiFi sítě, ke které se připojuje a po úspěšném připojení obdrženou IP adresu, pomocí které je možné RoboTommy rozeznat od dalších zařízení na síti.

## Ovládací program Command center
Start ovládacího programu pro Windows provedete spuštěním souboru "RoboTommy\Software\Chotěborky_2018_Remote_Control\RoboTommy Command Center-win32-x64/RoboTommy Command Center.exe". V nově otevřeném okně zadáte IP adresu RoboTommy, která je na něm zobrazena na OLED obrazovce.  Po kliknutí na tlačítko "Start" je možné ovládat pohyb RoboTommy pomocí kniplu, který se zobrazí držením levého tlačítka myši uvnitř okna Command Center. 

<figure>
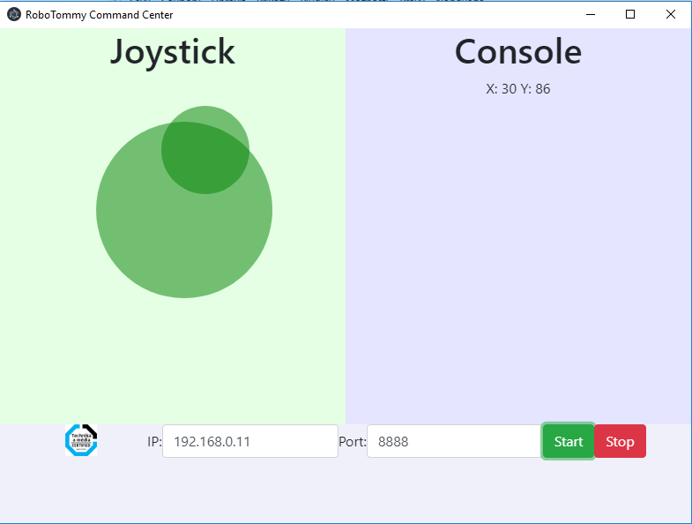
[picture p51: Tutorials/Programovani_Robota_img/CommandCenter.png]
    
    <figcaption></figcaption>
</figure>

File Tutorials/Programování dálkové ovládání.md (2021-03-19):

# Návod na programování RoboTommy - dálkové ovládání

V tomto návodě je popsána instalace vývojového prostředí, stažení tohoto repozitáře, nahrání připravených programů a také zprovoznění samotného dálkového ovládání platformy RoboTommy. Pro dálkové ovládání je Robotommy připojen ke stejné WiFi síti jako chytré zařízení sloužící jako ovladač.

Pro programování RoboTommy je použito vývojové prostředí [Visual Studio Code](https://code.visualstudio.com/download) s rozšířením PlatformIO. Pro instalaci prostředí a rozšíření můžeme použít tento [návod](https://docs.platformio.org/en/latest/ide/vscode.html#installation), jehož hlavní část je na obrázku níže:

<figure>
    
    <figcaption></figcaption>
</figure>

Pro naprogramování RoboTommy je třeba tento repozitář umístit do souborového systému vašeho PC a to buď stažením nebo naklonováním:
* Stažení pomocí kliku na tlačítko "Clone or download" vpravo na [hlavní stránce repozitáře](https://github.com/MarPta/RoboTommy) a následně "Download ZIP". Toto je jednodušší cesta pro začátečníky.
* Nakolonování pomocí [GIT](https://git-scm.com/downloads) a libovolného GIT klienta (GitHub Desktop, SourceTree).

## Arduino Nano ATmega328
Nejdříve naprogramujeme mikrokontrolér Arduino Nano. Projekt programu otevřeme v VS Code pomocí File->Open Folder->Zvolíme cestu "RoboTommy\Software\ArduinoNano". Tento program je možné bez úprav nahrát do RoboTommy. Arduino Nano zasunuté do MainBoard připojíme k PC pomocí USB Mini B kabelu. V případě použití neoriginálního Arduino klonu je třeba nainstalovat [driver CH340](https://sparks.gogo.co.nz/ch340.html). Dobrou praxí je ujistit se, že je Arduino detekováno v systémovém Správci zařízení. 

V levém spodním rohu VS Code se nachází panel PlatformIO. Je zde i tlačítko pro kompilaci a nahrání programu do Arduina (šipka směřující vpravo). Lze použít i klávesovou zkratku CTRL+ALT+U. V případě, že je připojeno více USB zařízení, budete ve spodním terminálu vyzvání k napsání názvu portu, pod kterým je Arduino vedeno, např. "COM11". Úspěšné nahrání programu je značeno velkým nápisem "SUCCESS" na spodním terminálu.

## ESP8266 WEMOS D1 mini
Mikrokontrolér ESP8266 budeme programovat na dvakrát. První program "ESP8266_test_calibration" slouží ke kalibraci gyroskopu a až řídicí program "ESP8266_webControl" umožňuje ovládání robota. 

Otevřeme projekt programu pro kalibraci RoboTommy z VS Code: File->Open Folder->Zvolíme cestu "RoboTommy\Software\ESP8266_test_calibration". Před nahráním programu do ESP8266 umístíme RoboTommy na vodorovnou podložku. Pomocí CTRL+ALT+U nahrajeme program do ESP8266 připojeného k PC pomocí micro USB kabelu. Po nahrání programu signalizovaného nápisem "SUCCESS" je vhodné ES8266 resetovat pomocí bočního tlačítka na WEMOS modulu (vedle nápisu RESET). Po restartu je na OLED obrazovce vypsáno, zda bylo úspěšné připojení gyroskopu MPU. V případě neúspěšného připojení odpoj a zapoj napájení (USB). Po úspěšném připojení MPU je spuštěna kalibrace, což je signalizováno nápisem "Calibration running". Nyní nesmíme s RoboTommy pohnout. Během jedné minuty se kalibrace dokončí s hláškou "Calibration done". Kalibrační data jsou uložena v paměti EEPROM (Electrically Erasable Programmable Read-Only Memory) a budou přečtena následujícím řídicím programem.

Otevřeme projekt programu pro řízení RoboTommy: File->Open Folder->Zvolíme cestu "RoboTommy\Software\ESP8266_webControl" a nahrajeme do ESP. Po restartu zobrazí úvodní obrazovka na OLED a vybídne nás k připojení k WiFi "RoboTommy". Použij libovolné chytré WiFi zařízení (mobil, tablet, PC) a najdi pomocí něj WiFi "RoboTommy". U novějších zařízení budeš následně vybídnut k přihlášení se do sítě, to udělej. U starších je třeba otevřít prohlížeč a zadat libovolnou URL (např. "osel.cz"). Následně se zobrazí konfigurační portál, ve kterém vybereš lokální (např. domácí) WiFi síť a zadáš její heslo. Po úspěšném připojení k lokální WiFi síti zobrazí RoboTommy svou přidělenou IP adresu na obrazovce.

Kromě samotného programu, který poběží na ESP8266, je do něj třeba také nahrát kód webové stránky, která se zobrazí a poběží v ovládacím zařízení. Ve VS Code necháme otevřený projekt "ESP8266_webControl" a spustíme PlatformIO terminál. Ten se spouští pomocí lišty nástrojů PlatformIO vlevo dole, kliknutím na tlačítko nejvíce v pravo s vyskakujícím popiskem "PlatformIO: New Terminal". Do Terminálu zadáme příkaz 
```
pio run -t uploadfs
```
 a potvrdíme klávesou enter. Počkáme dokud se proces nahrávání neukončí velkým nápisem "SUCCESS". Nyní můžeme ESP8266 odpojit od PC.

## Dálkové ovládání
Pro dálkové ovládání RoboTommy je možné opět použít libovolné chytré WiFi zařízení. S ním se připojíme na lokální WiFi, ke které je již RoboTommy připojen. Otevřeme internetový prohlížeč a do políčka pro URL adresu zadáme adresu IP, kterou nám RoboTommy ukazuje na své obrazovce, např. "192.168.1.211". Načte se nám webová stránka s joystickem ve spodní části. Pomocí něj řídíme RoboTommy. 

<figure>
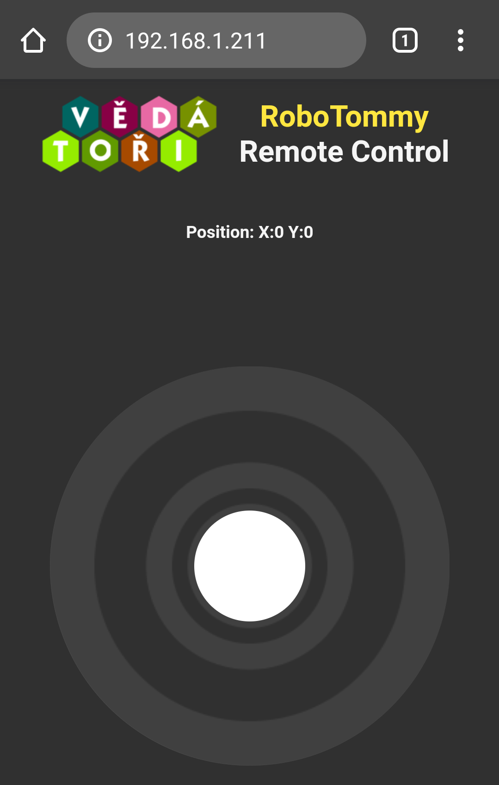
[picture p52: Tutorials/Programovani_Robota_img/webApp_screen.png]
    
    <figcaption></figcaption>
</figure>

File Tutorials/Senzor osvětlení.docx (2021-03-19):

Senzor osvětlení s LED

Funkce zapojení:

Toto zapojení rozsvěcí LED na desce v případě, že hladina okolního osvětlení klesne pod určenou mez. Tu je možné nastavit pomocí trimru. Dále poskytuje možnost čtení (nebo ovládání) výstupů z desky pomocí Arduina.

Pracovní postup:

Osazovat budeme podle velikosti součástek, tzn. že jako první budeme pájet nejmenší komponenty.


Jako první přijdou na řadu rezistory. Nemají danou polaritu (nezáleží, jaký vývod připojíme do jaké díry v desce). Pozor musíme dát na rozlišení hodnot podle barevného kódu:

100 R 5K6 10 K

Po připojení rezistorů by měla deska vypadat takto:


Dále připájíme tranzistor BC 547. Zde už musíme dávat pozor na polaritu – tranzistor má kolektor, bázi a emitor. Aby bylo osazení tranzistoru jednoznačné, stačí tranzistor usadit podle potisku desky – jednu stranu má plochou a druhou vyboulenou, jak je vidět na obrázku:


Dalším krokem je zapájení patice. Ta má z jedné strany viditelný výřez ve tvaru U. Ten je nutné dát k tomu konci nákresu integrovaného obvodu LM 358, u kterého je natisknuté kolečko označující vývod číslo 1. Orientaci ukazuje obrázek:


Nyní připájíme potenciometr. Ten stačí usadit do připraveného footprintu na desce a zapájet.


Jedním z posledních kroků je připájení LED diod. Ty mají polaritu, je potřeba je připájet vždy tak, aby delší vývod byl směřován k okraji desky. Pomoci může také tvar diody, který je z jedné strany plochý, což je vidět i na potisku desky:


Předposledním krokem bude zapájení kolíkové lišty. Tu budeme jako jedinou část pájet z druhé strany desky. Pozor, na obrázku je zahnutá kolíková lišta, ale napájejte klasickou přímou.


Poslední zapájenou součástkou bude fotorezistor, který nedáme co nejblíž desce, ale ponecháme ho až dva centimetry ve vzduchu na jeho vývodech:


Posledním krokem je vsadit integrovaný obvod LM 358 do patice. Strana s výřezem na IO musí být na straně výřezu na patici:


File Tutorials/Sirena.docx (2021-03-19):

Senzor osvětlení s LED

Funkce zapojení:

Po připojení napájecího napětí a připojení logické jedničky na vstup obvodu se spustí oscilátor s IO 555, který generuje obdélníkové pulzy. Ty jsou zesíleny tranzistorem, na který je připojen reproduktor, ze kterého pulzy slyšíme jako zvuk.

Pracovní postup:

Osazovat budeme podle velikosti součástek, tzn. že jako první budeme pájet nejmenší komponenty.


Jako první přijdou na řadu rezistory. Nemají danou polaritu (nezáleží, jaký vývod připojíme do jaké díry v desce). Pozor musíme dát na rozlišení hodnot podle barevného kódu:

1 K 10 K 12 K

Po připojení rezistorů by měla deska vypadat takto:


Nyní napájíme keramické kondenzátory. Nemají polaritu a oba mají stejnou hodnotu. Jejich rozteč je ale větší, než rozteč pájecích ploch, proto je potřeba vývody odpovídajícím způsobem nahnout.


Dále připájíme tranzistor BC 547. Zde už musíme dávat pozor na polaritu – tranzistor má kolektor, bázi a emitor. Aby bylo osazení tranzistoru jednoznačné, stačí tranzistor usadit podle potisku desky – jednu stranu má plochou a druhou vyboulenou, jak je vidět na obrázku:


Dalším krokem je zapájení patice. Ta má z jedné strany viditelný výřez ve tvaru U. Ten je nutné dát k tomu konci nákresu integrovaného obvodu NE 555, u kterého je natisknuté kolečko označující vývod číslo 1. Orientaci ukazuje obrázek:


Dalším krokem je odizolování a pocínování dvou vodičů délky asi 8 cm z obou stran. Pozor, nepoužívejte vodiče z reproduktorů, jsou nekvalitní a lámou se. Pokud se na konci vodičů tvoří kulička pájky, je možné ji odstřihnout.


Těmito vodiči nyní propojíme výstup „SP“ na desce s konektory na reproduktoru.


Nyní připájíme zahnutou kolíkovou lištu tak, aby piny směřovaly směrem ven z desky:


Posledním krokem je vsadit integrovaný obvod NE 555 do patice. Strana s výřezem na IO musí být na straně výřezu na patici:


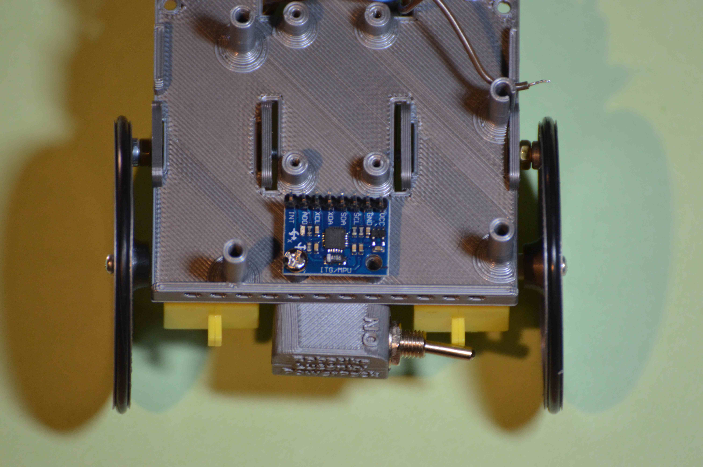
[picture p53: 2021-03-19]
Tutorials/SestaveniRobota_img/DSC_0089.JPG

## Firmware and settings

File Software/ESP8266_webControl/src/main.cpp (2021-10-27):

#include <Arduino.h>
#include <ESP8266WebServer.h>
#include <FS.h>
#include <ESP8266WiFi.h>
#include <DNSServer.h>            //Local DNS Server used for redirecting all requests to the configuration portal
#include <WiFiManager.h>          //https://github.com/tzapu/WiFiManager WiFi Configuration Magic
#include <ESP8266LLMNR.h>

#include "I2cDataProtocol.h"
#include "Gyroscope.h"
#include "StateVector.h"
#include "DifferentialChassis.h"
#include "DisplayClass.h"
#include "EEPROM_data.h"

ESP8266WebServer server(80);
WiFiManager wifiManager;
StateVector stateVector;
DisplayClass displayOLED;
DifferentialChassis chassis;
const char deviceName[] = "RoboTommy";
const char password[] = "adminadmin";
char passwordHash[33];
char cookieHash[42];

const uint8_t I2C_ADDRESS_NANO = 4;

const uint8_t CONTROL_PERIOD = 10;
uint32_t prevControlTime = 0;
const uint16_t communicationTimeout = 1000;
uint32_t prevCommunicationTime = 0;

int16_t gyroOffsets[6] = {0, }; //xAccel, yAccel, zAccel, xGyro, yGyro, zGyro
EEPROM_data gyroOffsetsEEPROM(gyroOffsets, 6*sizeof(gyroOffsets[0]));

bool is_authenticated() {
  Serial.println("Enter is_authenticated");
  if (server.hasHeader("Cookie")) {
    String cookie = server.header("Cookie");
    if (cookie.indexOf(cookieHash) != -1) {
      Serial.println("Authentication Successful");
      return true;
    }
  }
  Serial.println("Authentication Failed");
  return false;
}

void handleLogin() {
    String msg;
    if (server.hasHeader("Cookie")) {
        Serial.print("Found cookie: ");
        String cookie = server.header("Cookie");
        Serial.println(cookie);
    }
    if (server.hasArg("DISCONNECT")) {
        Serial.println("Disconnection");
        server.sendHeader("Location", "/login");
        server.sendHeader("Cache-Control", "no-cache");
        server.sendHeader("Set-Cookie", "ESPSESSIONID=0");
        server.send(301);
        return;
    }
    if (server.hasArg("PASSWORD")) {
        if (server.arg("PASSWORD") == password) {
        server.sendHeader("Location", "/");
        server.sendHeader("Cache-Control", "no-cache");
        server.sendHeader("Set-Cookie", cookieHash);
        server.send(301);
        Serial.println("Log in Successful");
        return;
        }
        msg = "Wrong password! try again.";
        Serial.println("Log in Failed");
    }
    File f = SPIFFS.open("/login.html", "r");
    server.streamFile(f, "text/html");
    f.close();
}

void handleRoot() {
    String header;
    if (!is_authenticated()) {
        server.sendHeader("Location", "/login");
        server.sendHeader("Cache-Control", "no-cache");
        server.send(301);
        return;
    }

    File f = SPIFFS.open("/webApp.html", "r");
    server.streamFile(f, "text/html");
    f.close();
}

void handleNotFound() {
    File f = SPIFFS.open("/notFound.html", "r");
    server.streamFile(f, "text/html");
    f.close();
}
void handleJSData() {
    stateVector.joystickX = server.arg(0).toInt();
    stateVector.joystickY = server.arg(1).toInt();

    server.send(200, "text/plain", ""); //return an HTTP 200 (OK)
    prevCommunicationTime = millis();
}

void setup() {
    Serial.begin(115200);
    delay(1000);
    exSonarDist.setVarAddress(&(stateVector.sonarDistance));
    exEngineLeftSpeed.setVarAddress(&(stateVector.engineLeftSpeed));
    exEngineRightSpeed.setVarAddress(&(stateVector.engineRightSpeed));
    I2cExchangeData::beginMaster(I2C_ADDRESS_NANO);

    displayOLED.init();
    displayOLED.writeWelcome();
    delay(1000);
    char textOut[80];
    sprintf(textOut, "Connect to %s WiFi to pass credentials of local WiFi", deviceName);
    displayOLED.writeString(textOut);

    //WiFi.mode(WIFI_AP);
    WiFi.hostname(deviceName);
    wifiManager.autoConnect(deviceName);
    LLMNR.begin(deviceName);
    //IPAddress Ip(192, 168, 1, 1);
    //IPAddress NMask(255, 255, 255, 0);
    /*WiFi.softAPConfig(Ip, Ip, NMask);
    if(!WiFi.softAP(deviceName, password)) {
        Serial.println("WiFi.softAP failed.(Password too short?)");
        return;
    }*/

    sprintf(textOut, "Connect to %s WiFi and http://%s or IP %s", WiFi.SSID().c_str(), deviceName, WiFi.localIP().toString().c_str());
    displayOLED.writeString(textOut);

    Serial.print("WiFi connected, IP address:");
    Serial.println(WiFi.localIP());

    MD5Builder md5;
    md5.begin();
    md5.add(password);
    md5.calculate();
    md5.getChars(passwordHash);
    sprintf(cookieHash, "psdHash=%s", passwordHash);

    if (!SPIFFS.begin()) {
        Serial.println("SPIFFS Mount failed");
    } 
    else {
        Serial.println("SPIFFS Mount succesfull");
    }
    server.on("/", handleRoot);
    server.serveStatic("/style.css", SPIFFS, "/style.css");
    server.on("/login", handleLogin);
    server.on("/jsData.html", handleJSData);
    server.onNotFound(handleNotFound);

    //here the list of headers to be recorded
    const char * headerkeys[] = {"Cookie"} ;
    size_t headerkeyssize = sizeof(headerkeys) / sizeof(char*);
    //ask server to track these headers
    server.collectHeaders(headerkeys, headerkeyssize);
    server.begin();

    gyroOffsetsEEPROM.read();
    initiateGyroscope(gyroOffsets);
    chassis.setDirSpeed(0, 0);
}

void loop()
{
    server.handleClient();
    if(millis() > prevControlTime + CONTROL_PERIOD) {
        prevControlTime = millis();

        //Get Inputs
        I2cExchangeData::exchange();
        updateGyroData(stateVector.ypr);

        //Automatic Control
        if(millis() > prevCommunicationTime + communicationTimeout) {
            stateVector.joystickX = 0;
            stateVector.joystickY = 0;
        }
        chassis.setDirSpeed(stateVector.direction, stateVector.speed);

        //Set Outputs
        chassis.updateOutput(stateVector.ypr[0]);
        //stateVector.engineLeftSpeed = chassis.getLeftSpeed();
        //stateVector.engineRightSpeed = chassis.getRightSpeed();
        stateVector.engineLeftSpeed = (stateVector.joystickY + ((stateVector.joystickY >= 0) ? 1 : -1) * stateVector.joystickX) * 2.55;
        stateVector.engineRightSpeed = (stateVector.joystickY - ((stateVector.joystickY >= 0) ? 1 : -1) * stateVector.joystickX) * 2.55;

        stateVector.engineLeftSpeed = constrain(stateVector.engineLeftSpeed, -255, 255);
        stateVector.engineRightSpeed = constrain(stateVector.engineRightSpeed, -255, 255);

        //Serial.printf("%d %d\n", stateVector.engineLeftSpeed, stateVector.engineRightSpeed);
        //Serial.printf("%f, %f, %f\n", stateVector.ypr[0], stateVector.ypr[1], stateVector.ypr[2]);
    }
}

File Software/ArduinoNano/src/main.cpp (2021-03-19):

#include <Arduino.h>
#include <NewPing.h>
#include "Engine.h"
#include "StateVector.h"
#include "I2cDataProtocol.h"

#define ENGINE_LEFT_A 6
#define ENGINE_LEFT_B 9
#define ENGINE_RIGHT_A 10
#define ENGINE_RIGHT_B 11

#define SONAR_TRIGGER_PIN 7
#define SONAR_ECHO_PIN 8
#define SONAR_MAX_DISTANCE 100  //[cm]

#define I2C_ADDRESS 4
#define ACTIVE_MASTER_DELAY 300 //[ms]

Engine engineLeft(ENGINE_LEFT_A, ENGINE_LEFT_B);
Engine engineRight(ENGINE_RIGHT_A, ENGINE_RIGHT_B);

NewPing sonar(SONAR_TRIGGER_PIN, SONAR_ECHO_PIN, SONAR_MAX_DISTANCE);
StateVector stateVector;

void setup() {
    Serial.begin(115200);
    exSonarDist.setVarAddress(&stateVector.sonarDistance);
    exEngineLeftSpeed.setVarAddress(&stateVector.engineLeftSpeed);
    exEngineRightSpeed.setVarAddress(&stateVector.engineRightSpeed);
    I2cExchangeData::beginSlave(I2C_ADDRESS, ACTIVE_MASTER_DELAY);

}
void loop() {
    //Get inputs
    stateVector.sonarDistance = sonar.ping_cm();
    if(I2cExchangeData::isMasterActive() == false){
        stateVector.engineLeftSpeed = 0;
        stateVector.engineRightSpeed = 0;
    }

    //Set outputs
    engineLeft.setSpeed(stateVector.engineLeftSpeed);
    engineRight.setSpeed(stateVector.engineRightSpeed);
    Serial.println(stateVector.engineLeftSpeed);
    delay(20);
}

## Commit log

2021-03-19 Initial commit. General repository update.
    [CNY70Fastener - Part 1.stl, CNY70Holder - Part 1 (1).stl, DisplayHolder - Part 1.stl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]
2021-10-27 Fixed String compilation error and Macos include path error.
    [main.cpp]
